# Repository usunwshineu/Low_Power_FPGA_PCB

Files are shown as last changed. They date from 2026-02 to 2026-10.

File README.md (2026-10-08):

# ICE40UP5K LOW POWER FPGA BOARD 

## PCB design

A custom low-power FPGA development board based on the Lattice iCE40UP5K FPGA. 
The board was designed to provide FPGA processing capabilities together with 
power monitoring and common communication interfaces.

The board contains:
* ICE40UP5K FPGA
* FTDI USB interface
* 12MHz clock (used for both the FPGA and FTDI)
* INA226 sensors for measuring power consumption
* I2C and SPI mode 0 PMODs
* SPI Flash memory
* I/O pins
* a reset button
* 3 buttons
* 4 LEDs and 1 RGB LED
  
For different SPI modes you can check <a href="https://0x04.net/~mwk/sbdocs/ice40/FPGA-TN-02010-1-8-iCE40-I2C-and-SPI-Hardened-IP-User-Guide.pdf">this document.

The final assembled board:
Assembled

## PCB programming 

I checked the functionality of the board by running some simple verilog and I used icestorm for creating the bitstream. 
You can check more about Project IceStorm here <a href="https://0x04.net/~mwk/sbdocs/ice40/FPGA-TN-02010-1-8-iCE40-I2C-and-SPI-Hardened-IP-User-Guide.pdf](https://prjicestorm.readthedocs.io/en/latest/overview.html#what-is-project-icestorm">.

The commands I used were: 
* yosys -p "synth_ice40 -top top -json module.json" module.v -> for synthesizing the verilog design
* nextpnr-ice40 --up5k --package sg48 --json module.json --pcf pins.pcf --asc module.asc -> place-and-route
* icepack module.asc module.bin -> converting the result into binary bitstream
* iceprog module.bin -> programming the SPI Flash

Replace module.v, module.json, module.asc, module.bin, and pins.pcf with the corresponding filenames for your design.

## Adding a microprocessor

I used this particular RISC V system, which was built specifically for iCE40UP5k FPGAs: <a href="https://github.com/emeb/up5k_riscv/blame/master/README.md">up5k_riscv.

I modified the icestorm/up5k_riscv.pcf file with my own pins. Any other modified files were added to this repository.
In main.c file I wrote a code to read the power consumption (using I2C communication with the INA226 sensors) and display it on an OLED (SPI communication). 

This provides a complete demonstration of the board's:

* RISC V processing system
* I2C communication
* SPI communication
* Power monitoring
* OLED display interface

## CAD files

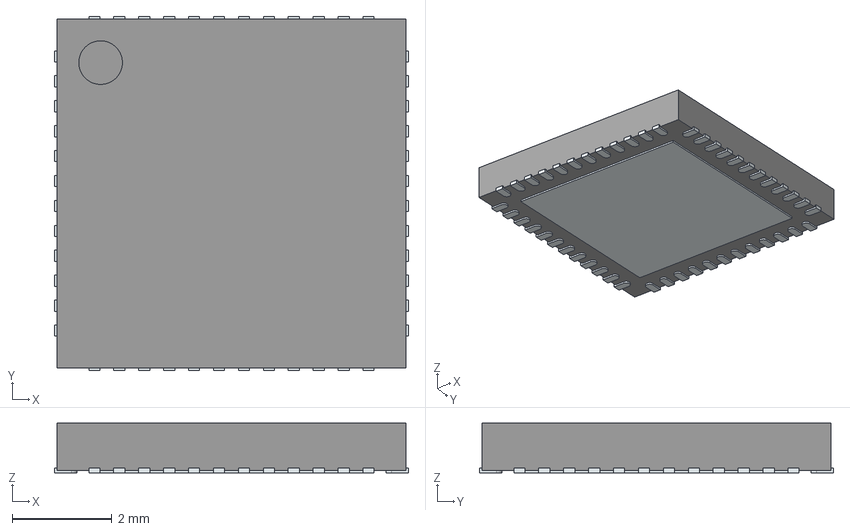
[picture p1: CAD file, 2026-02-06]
librarii/ICE5LP2K-SG48ITR/3D/ICE5LP2K-SG48ITR.stp
7.10 x 7.10 x 1.00 mm
ThermalPin
PinsArrayLR
PinsArrayTB

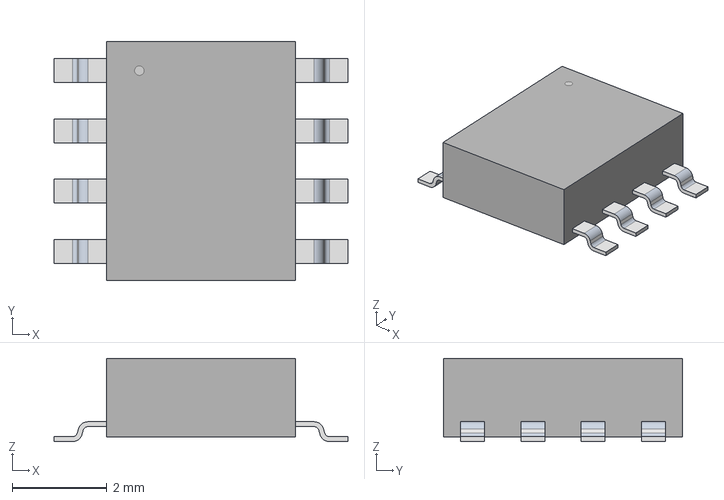
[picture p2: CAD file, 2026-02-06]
librarii/SOP8_150MIL_MAC.iges
6.20 x 5.03 x 1.75 mm

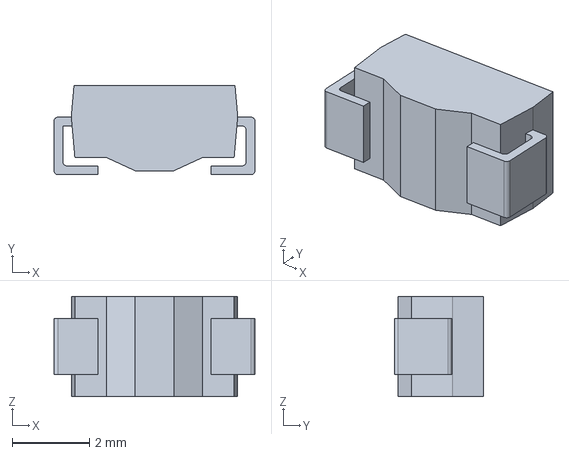
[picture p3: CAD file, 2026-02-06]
librarii/TVS_DIODE/SMAJ5.0A/3D/SMAJ5.0A.stp
5.21 x 2.31 x 2.60 mm

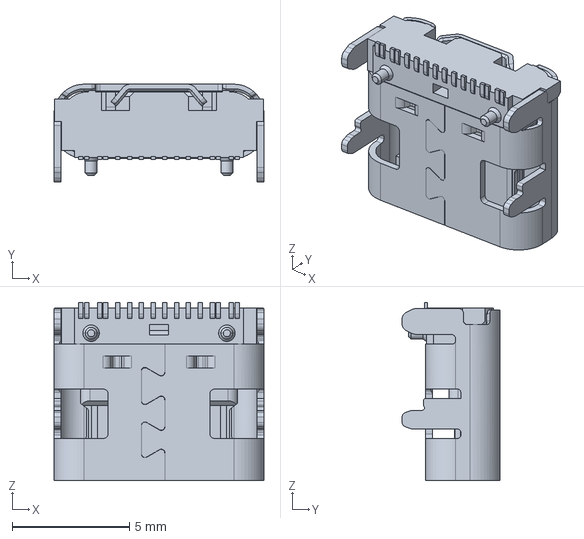
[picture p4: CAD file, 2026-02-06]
librarii/USB-C_connector/10155435-00011LF/3D/10155435-00011LF.stp
8.94 x 4.16 x 7.60 mm

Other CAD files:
librarii/ICE5LP2K-SG48ITR/Allegro/qfn50p700x700x100-49n-d.psm
librarii/ICE5LP2K-SG48ITR/DEHDL/ice5lp2k_sg48itr/chips/chips.prt
librarii/TVS_DIODE/SMAJ5.0A/Allegro/diom5026x229n.psm
librarii/TVS_DIODE/SMAJ5.0A/DEHDL/smaj5.0a/chips/chips.prt

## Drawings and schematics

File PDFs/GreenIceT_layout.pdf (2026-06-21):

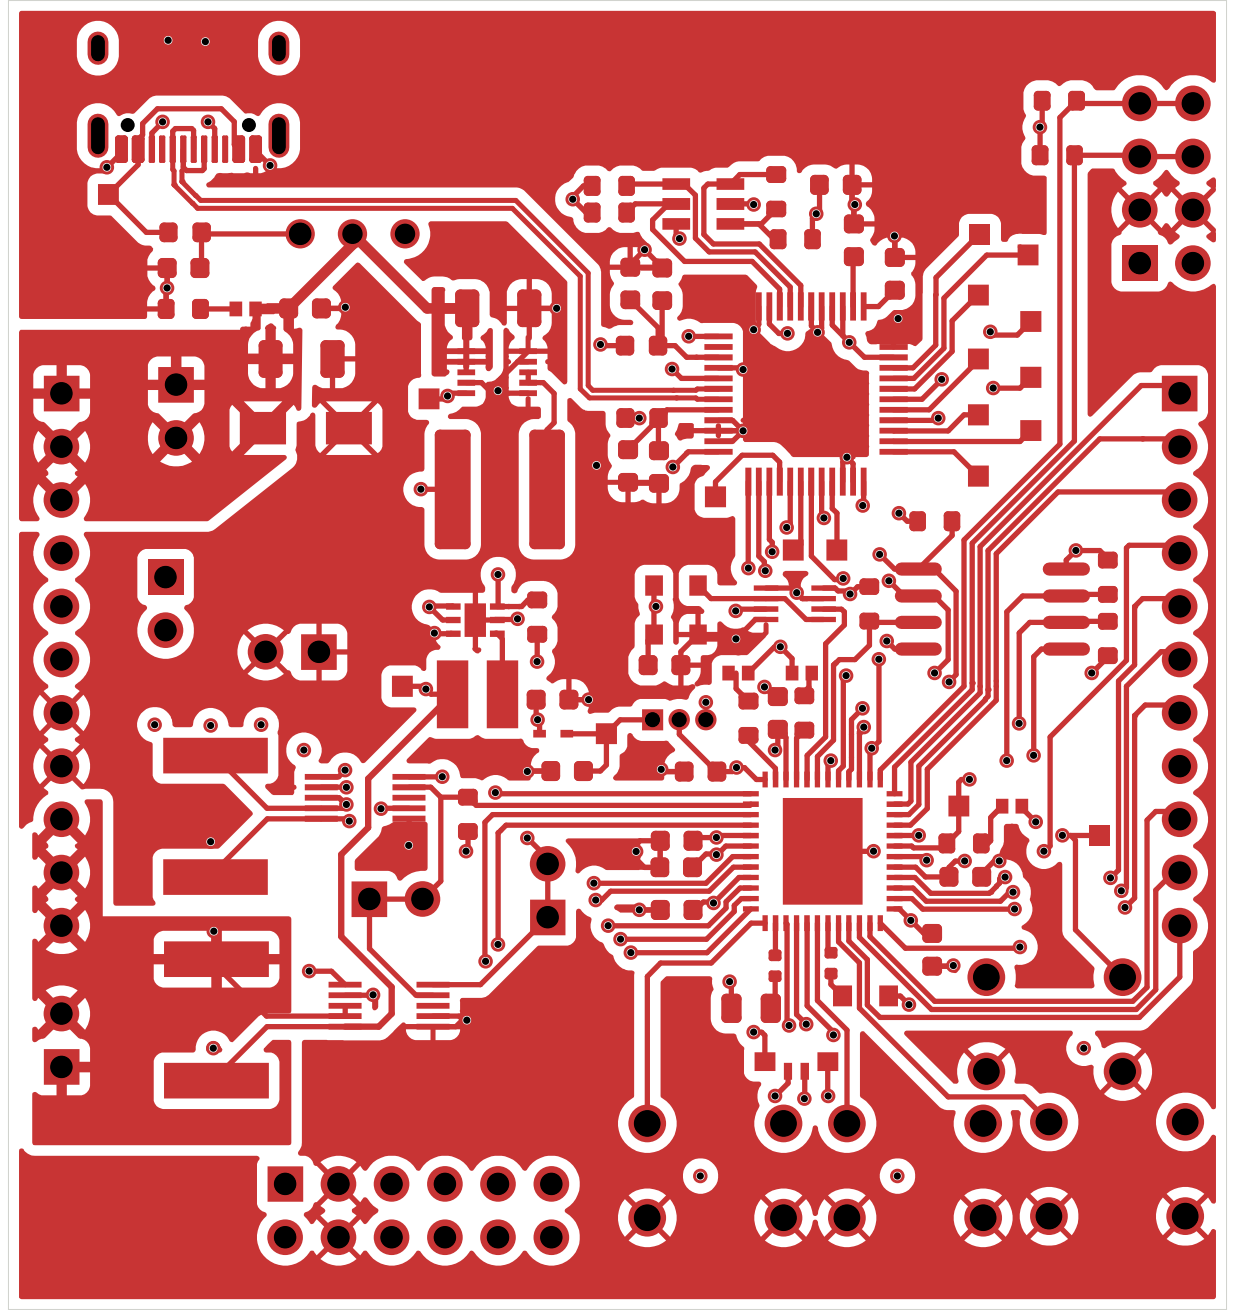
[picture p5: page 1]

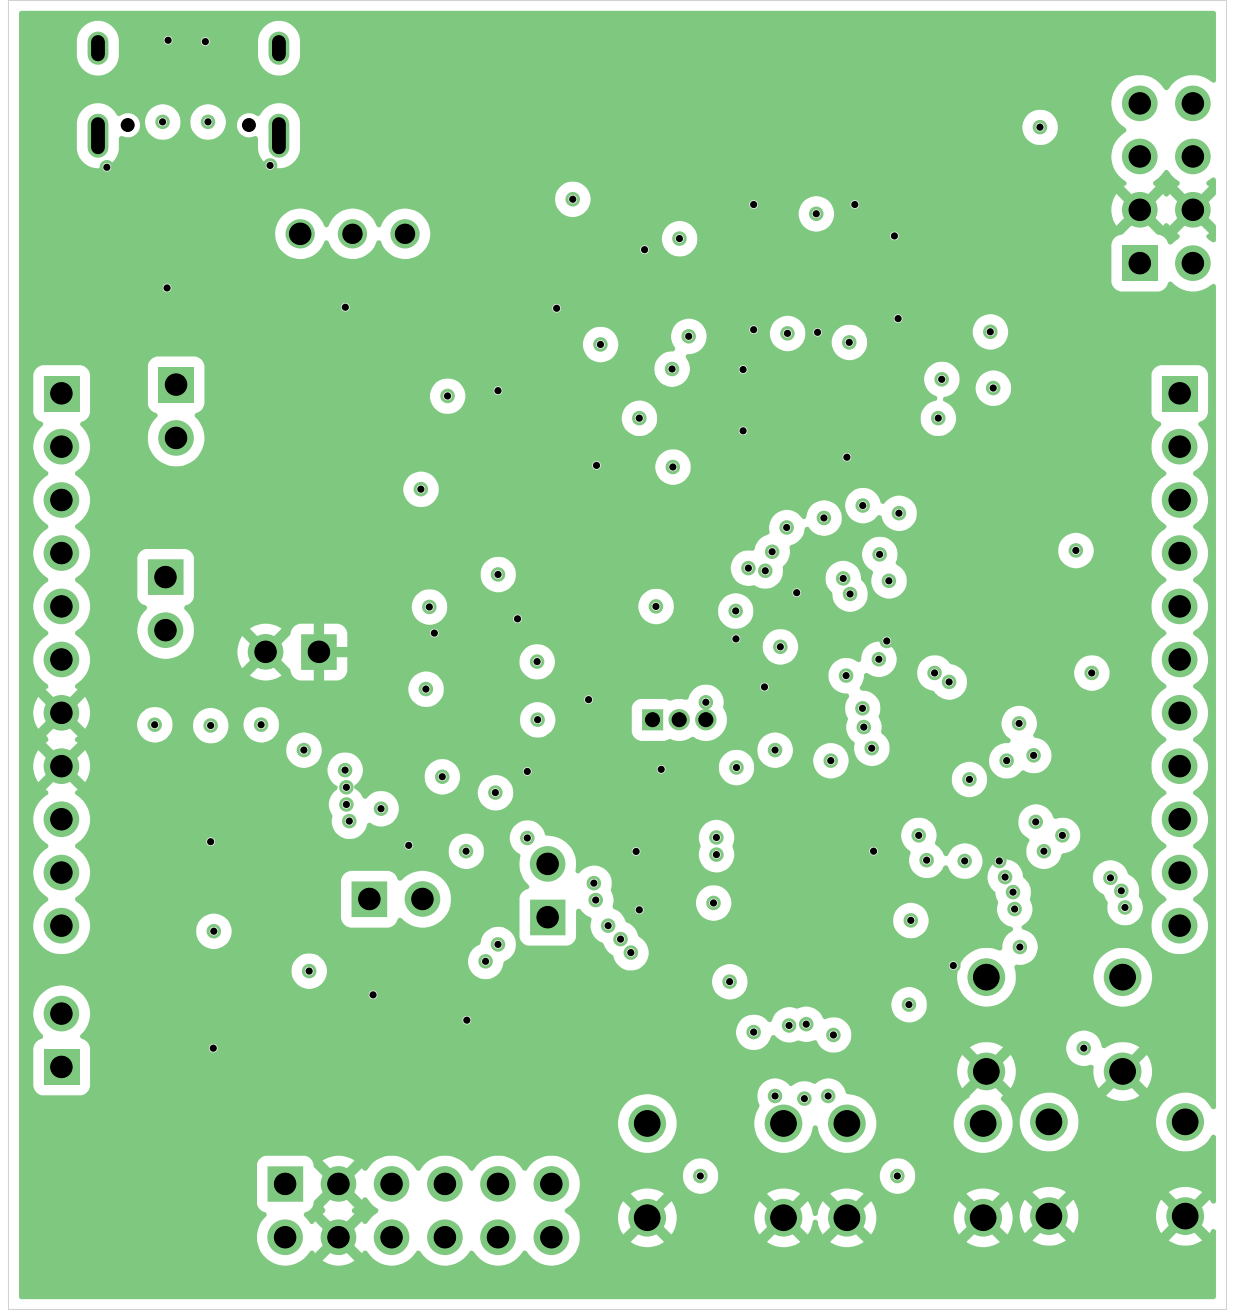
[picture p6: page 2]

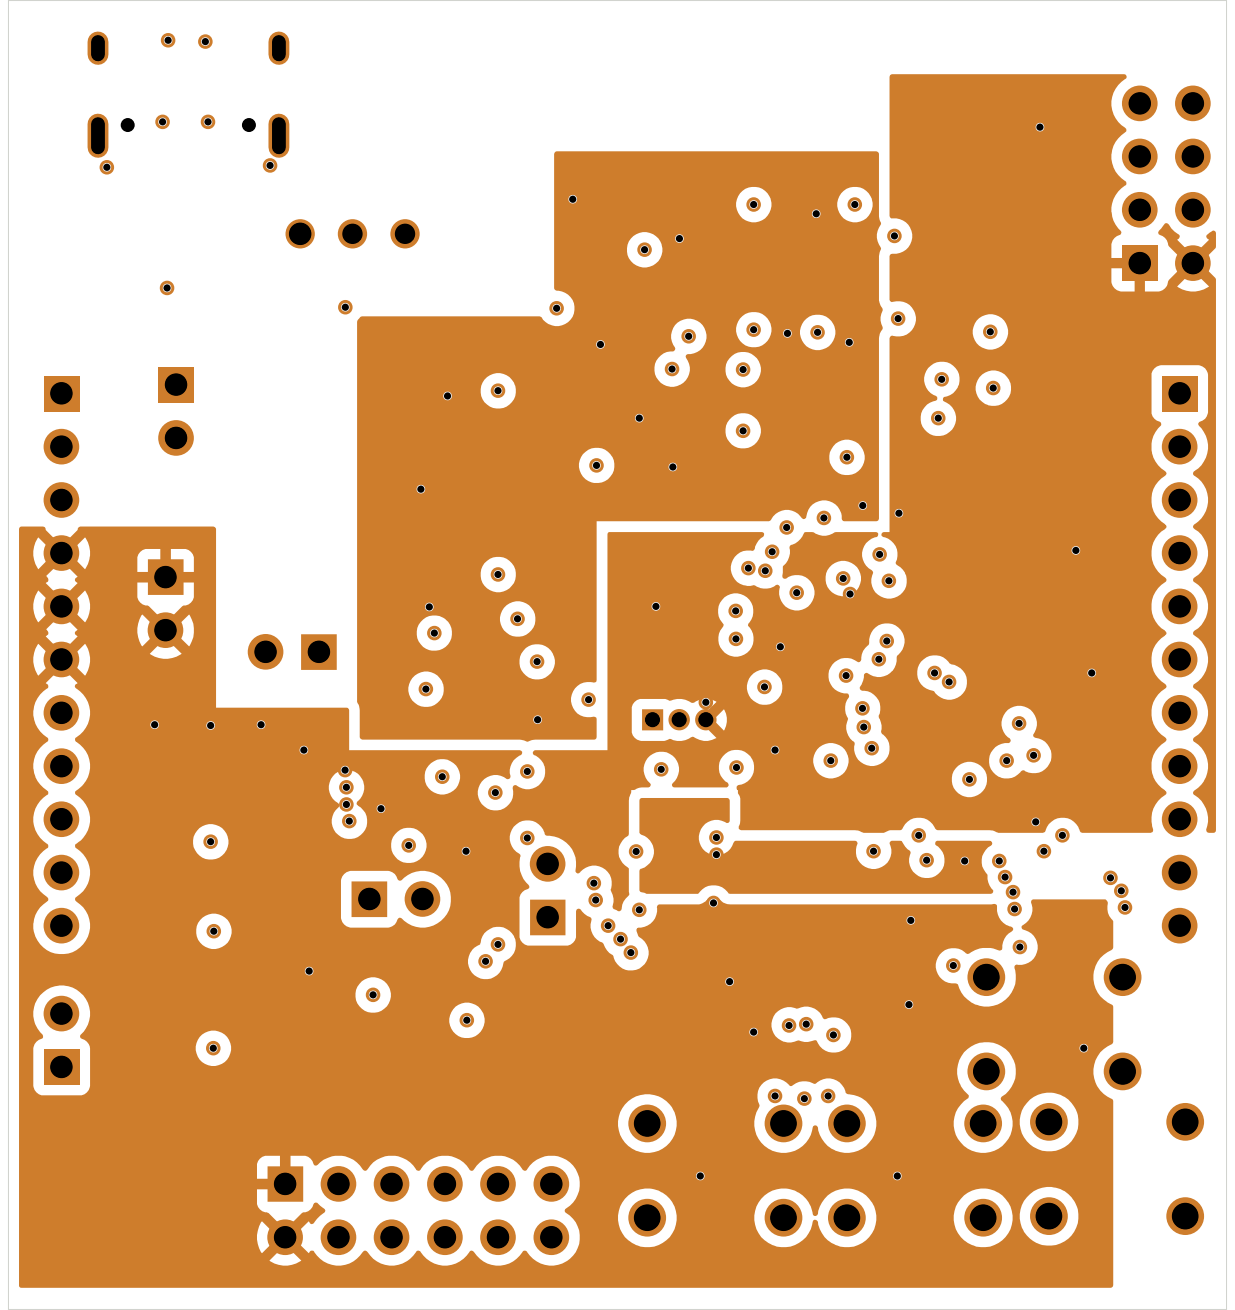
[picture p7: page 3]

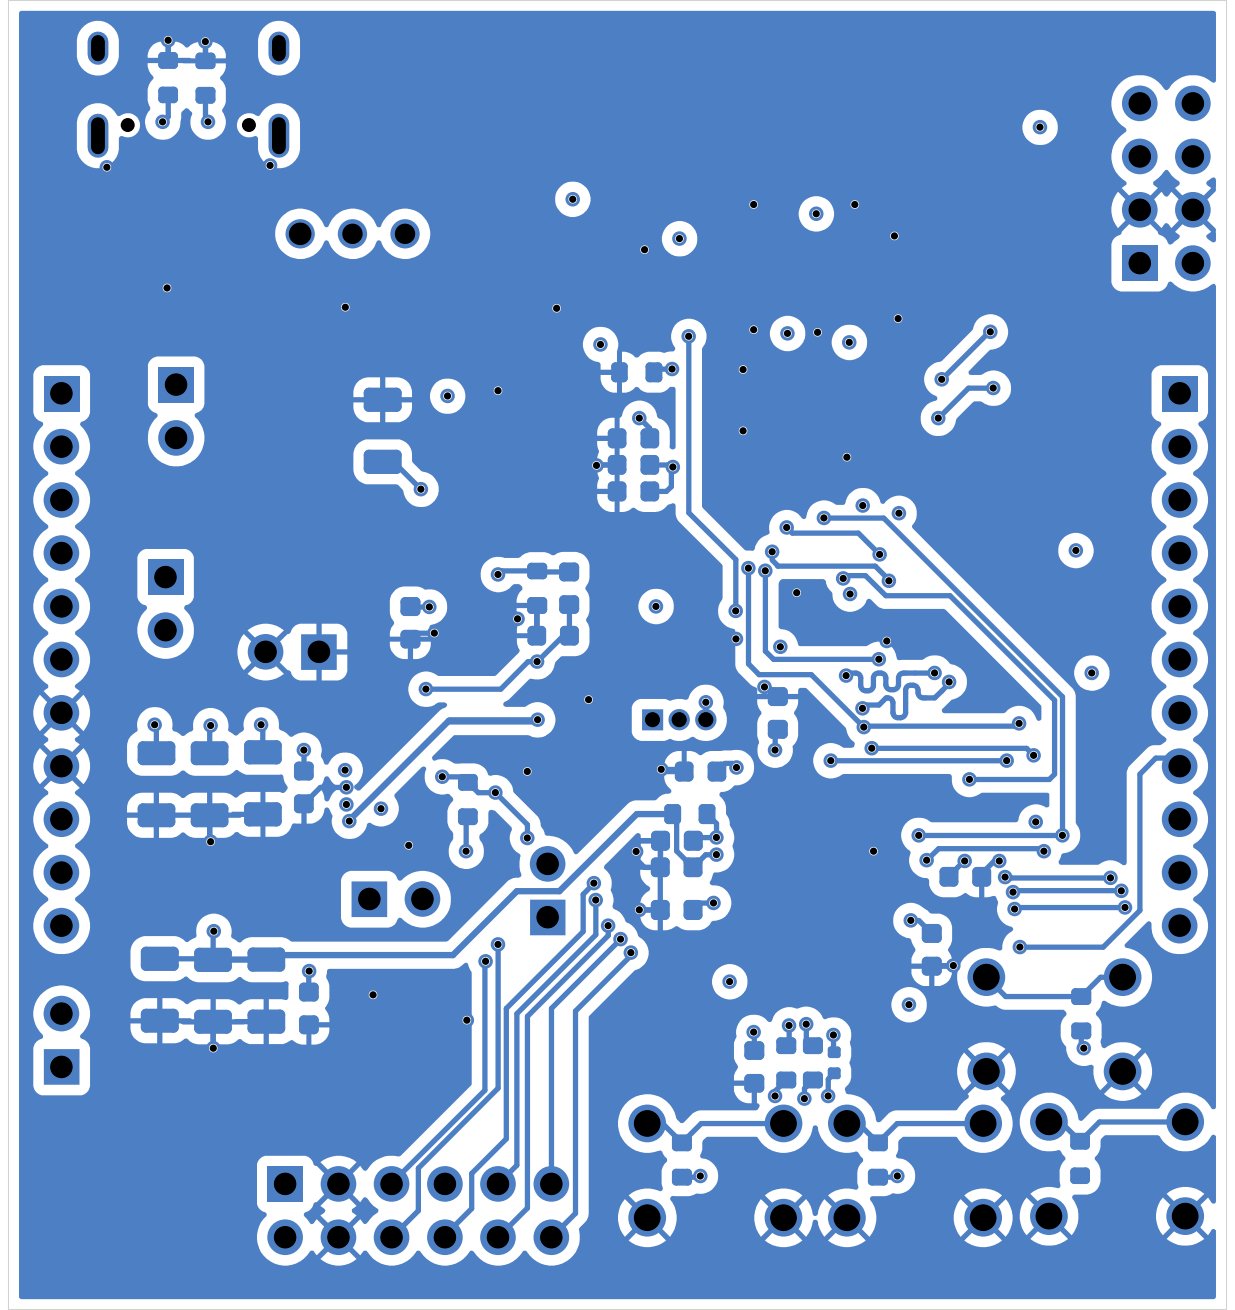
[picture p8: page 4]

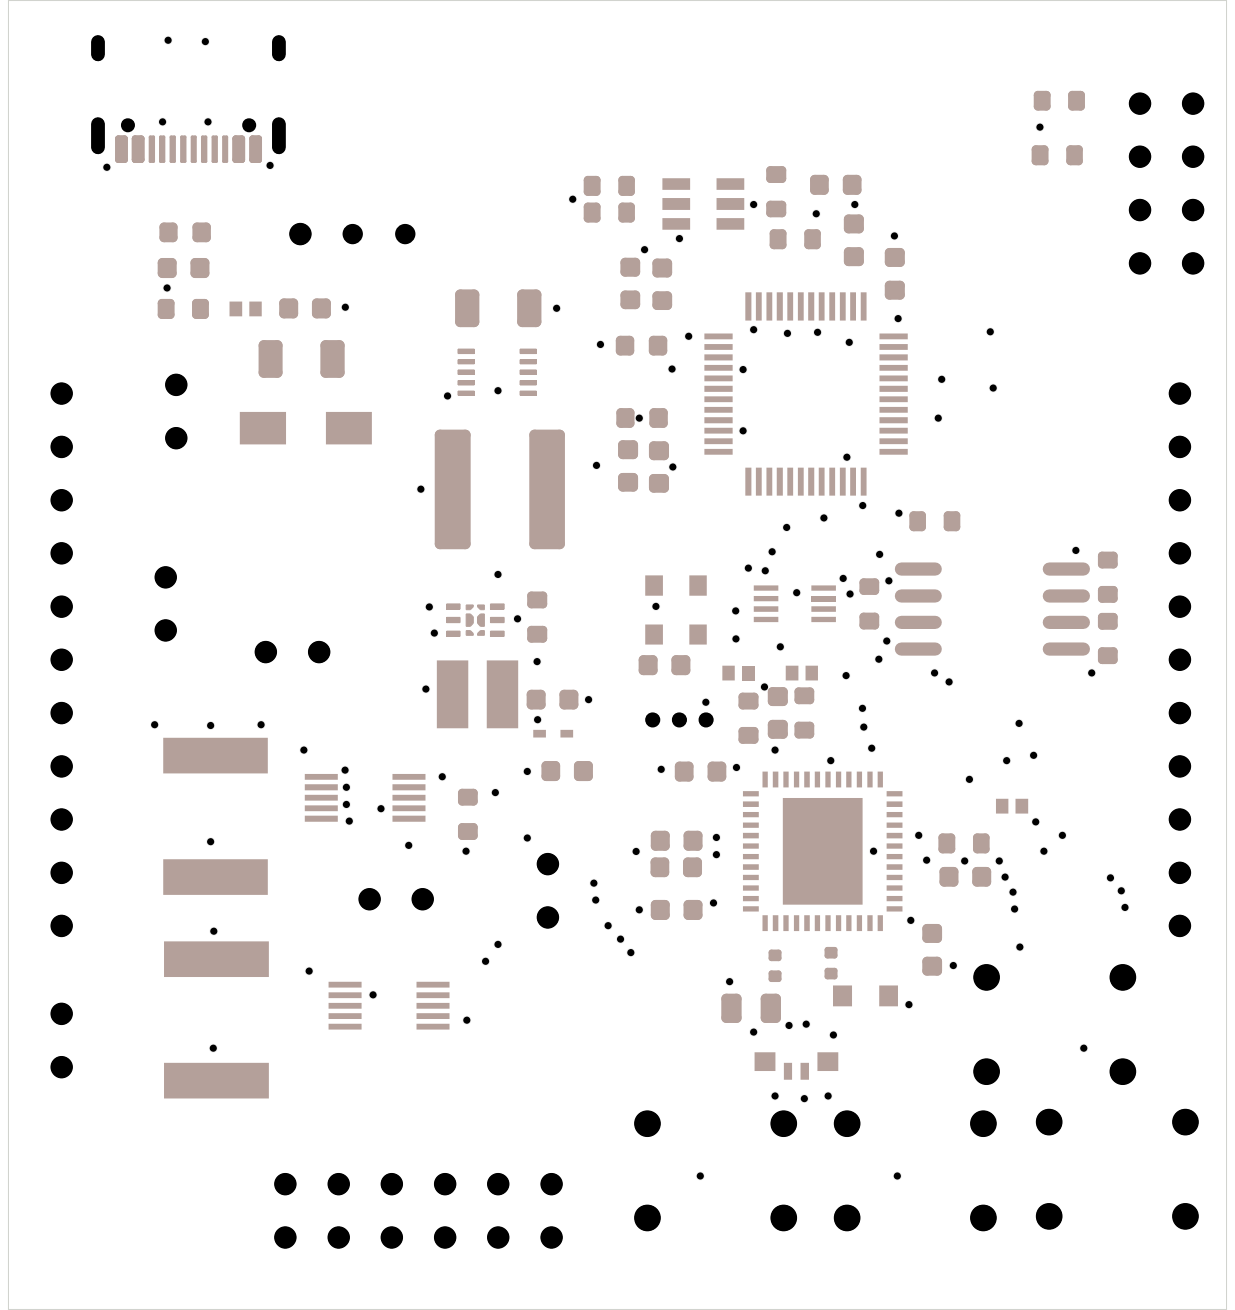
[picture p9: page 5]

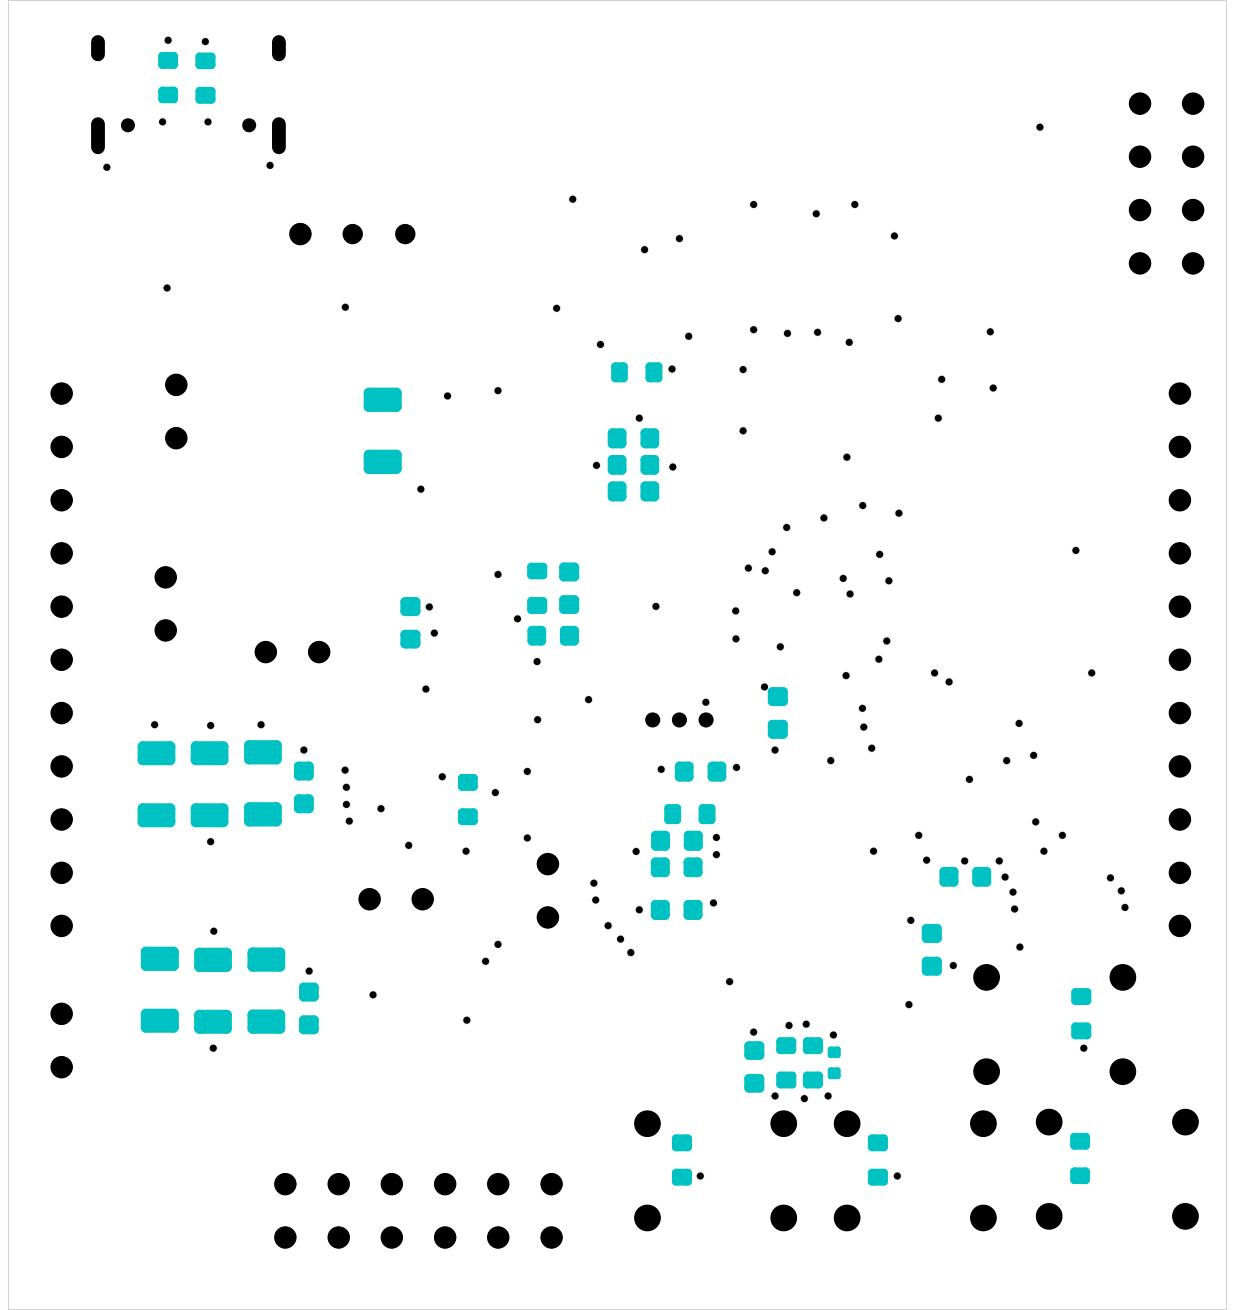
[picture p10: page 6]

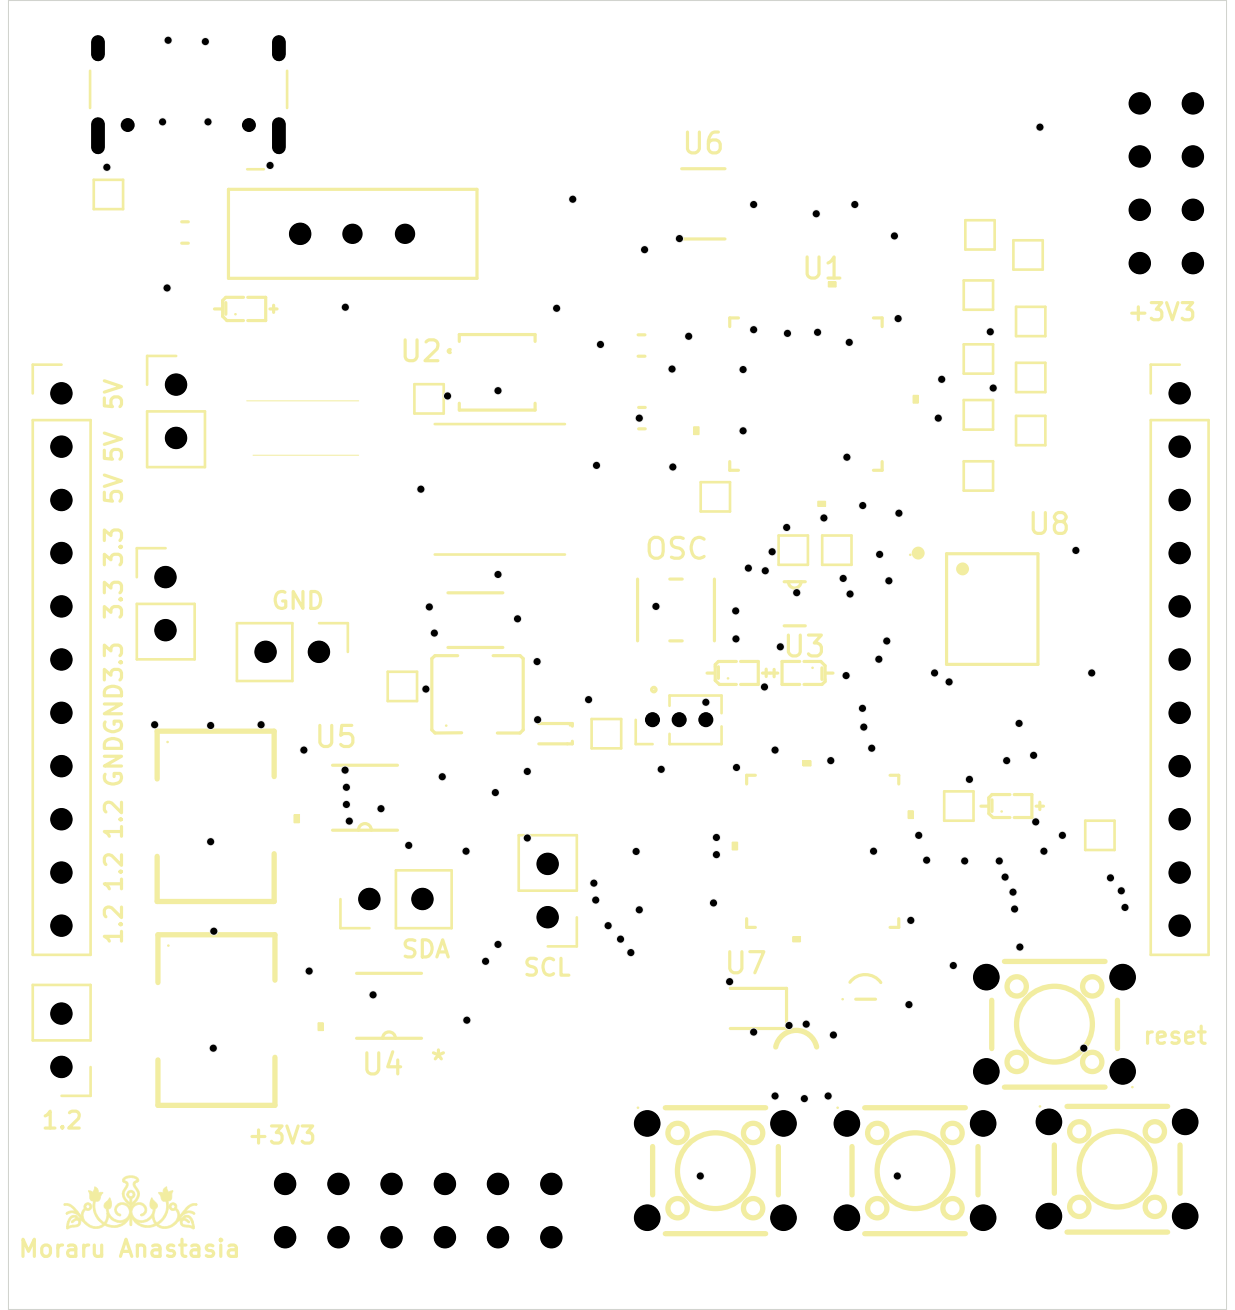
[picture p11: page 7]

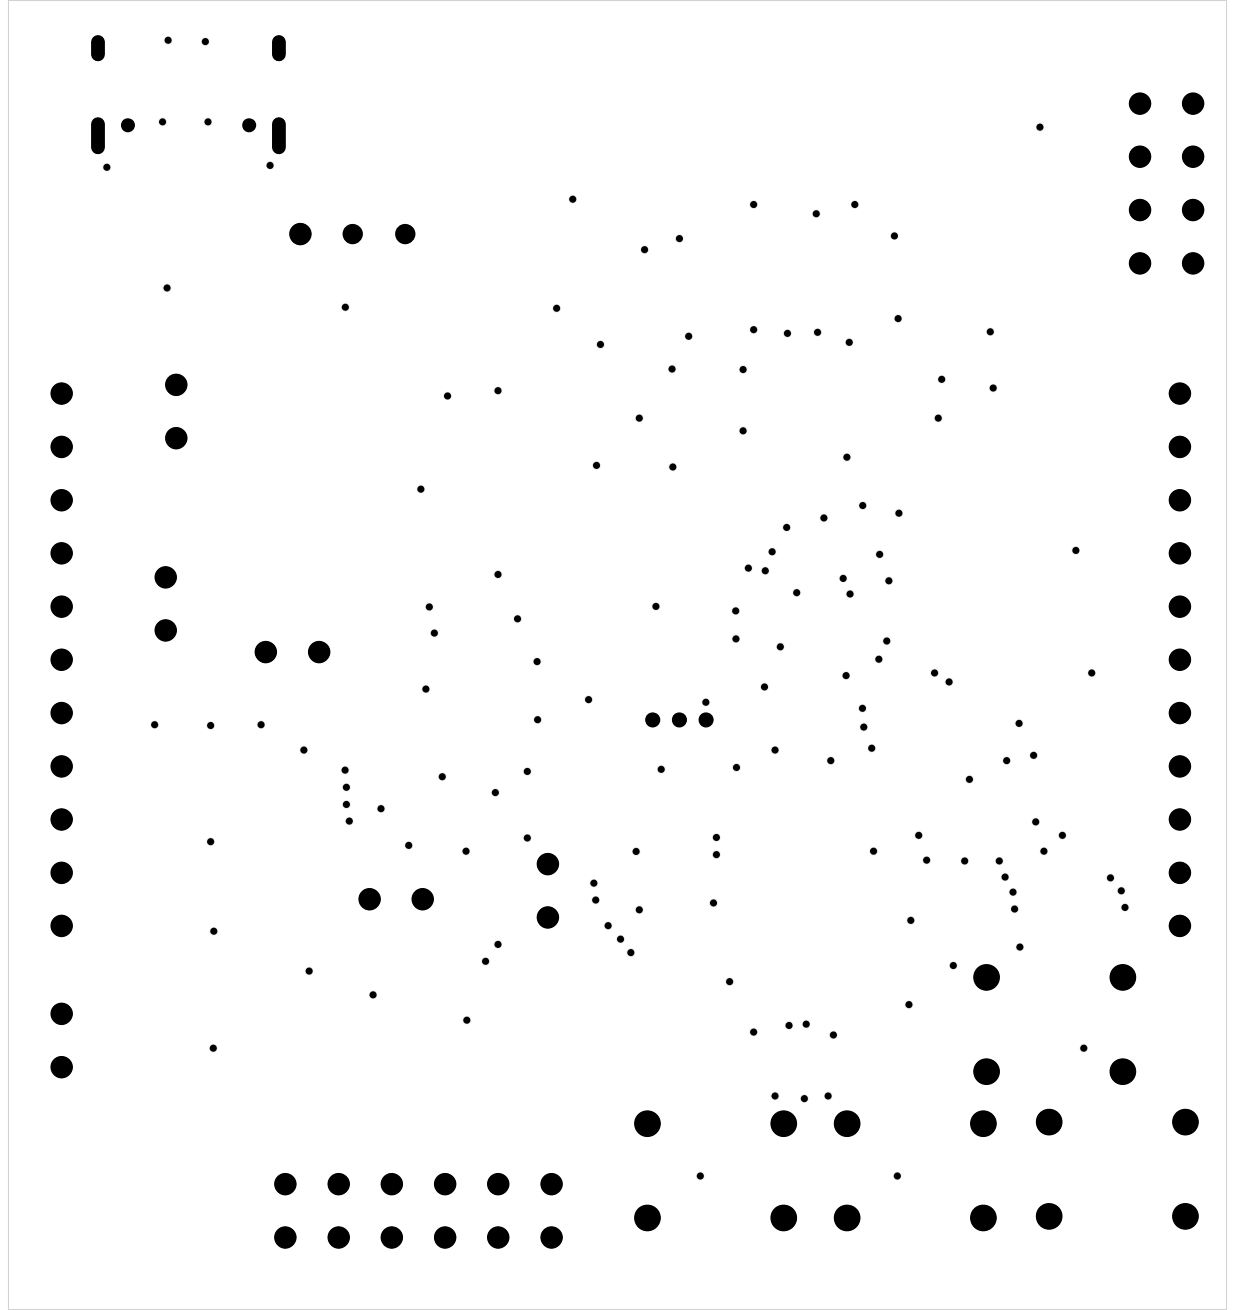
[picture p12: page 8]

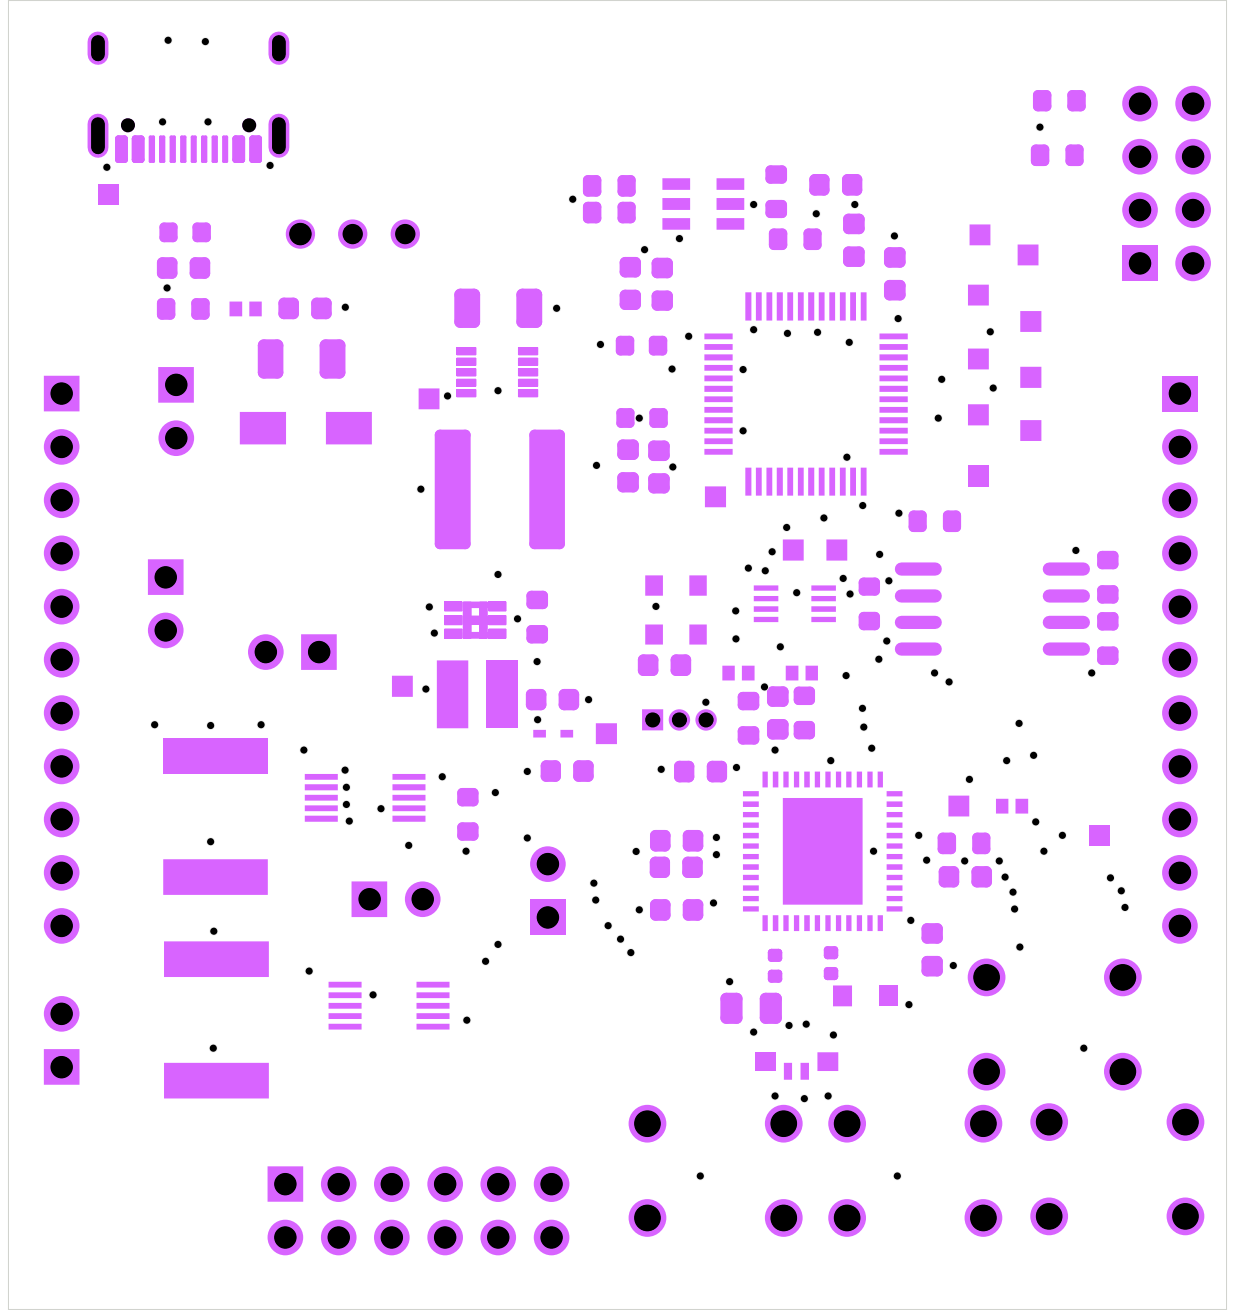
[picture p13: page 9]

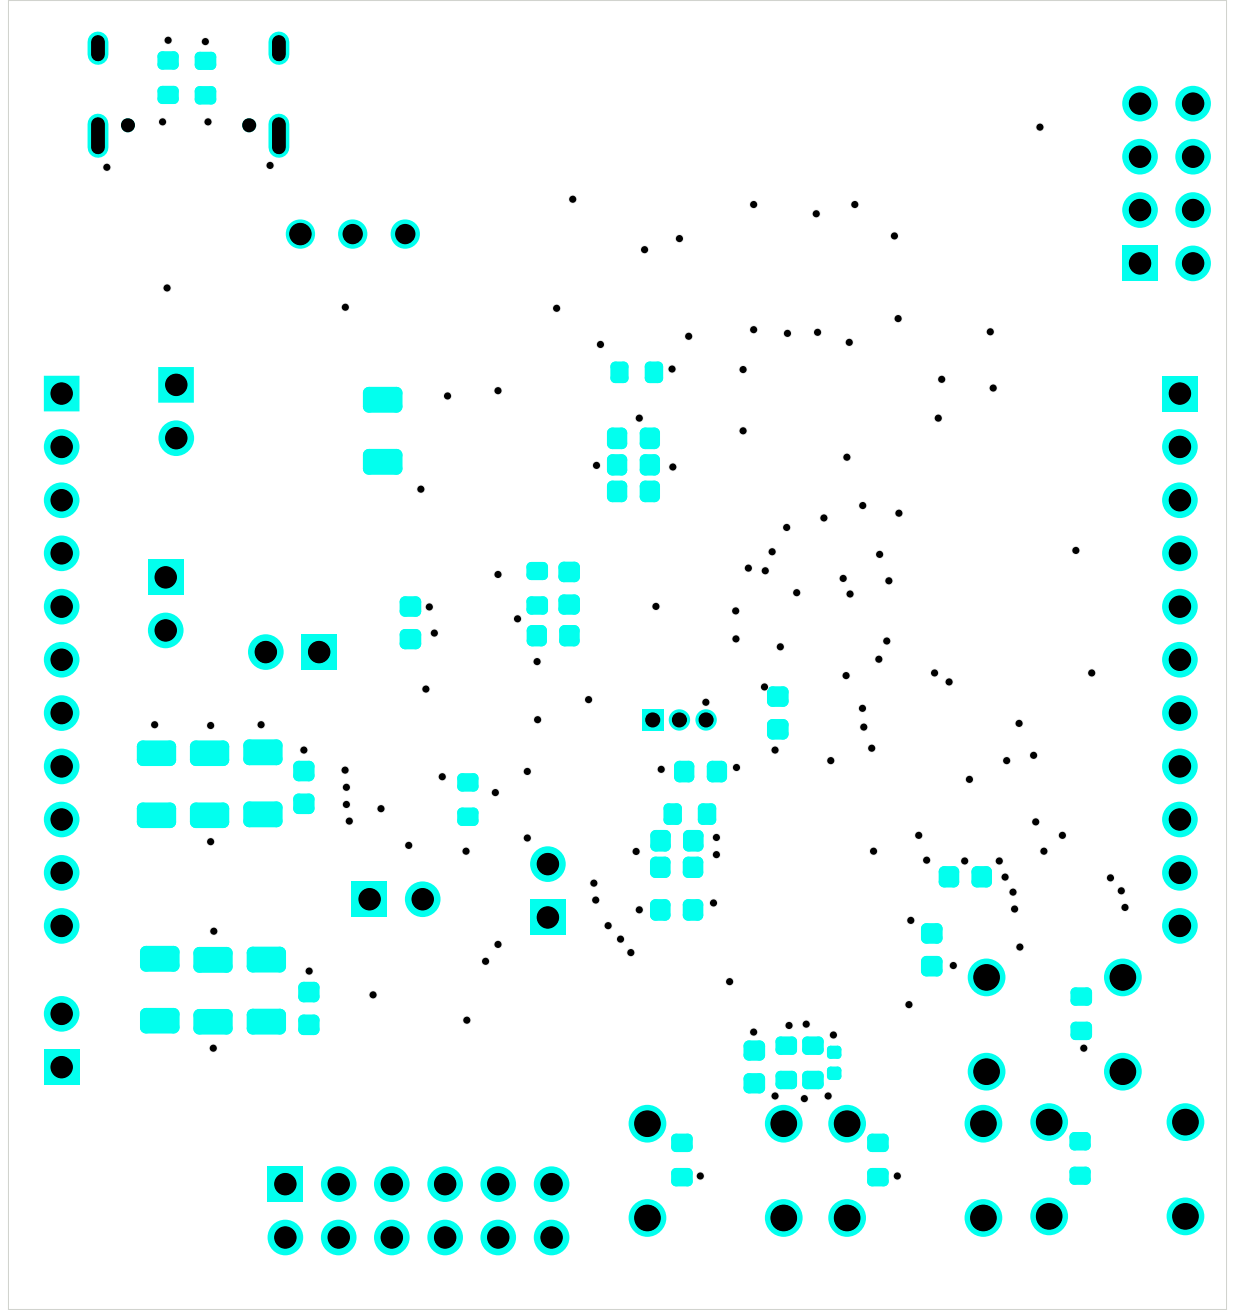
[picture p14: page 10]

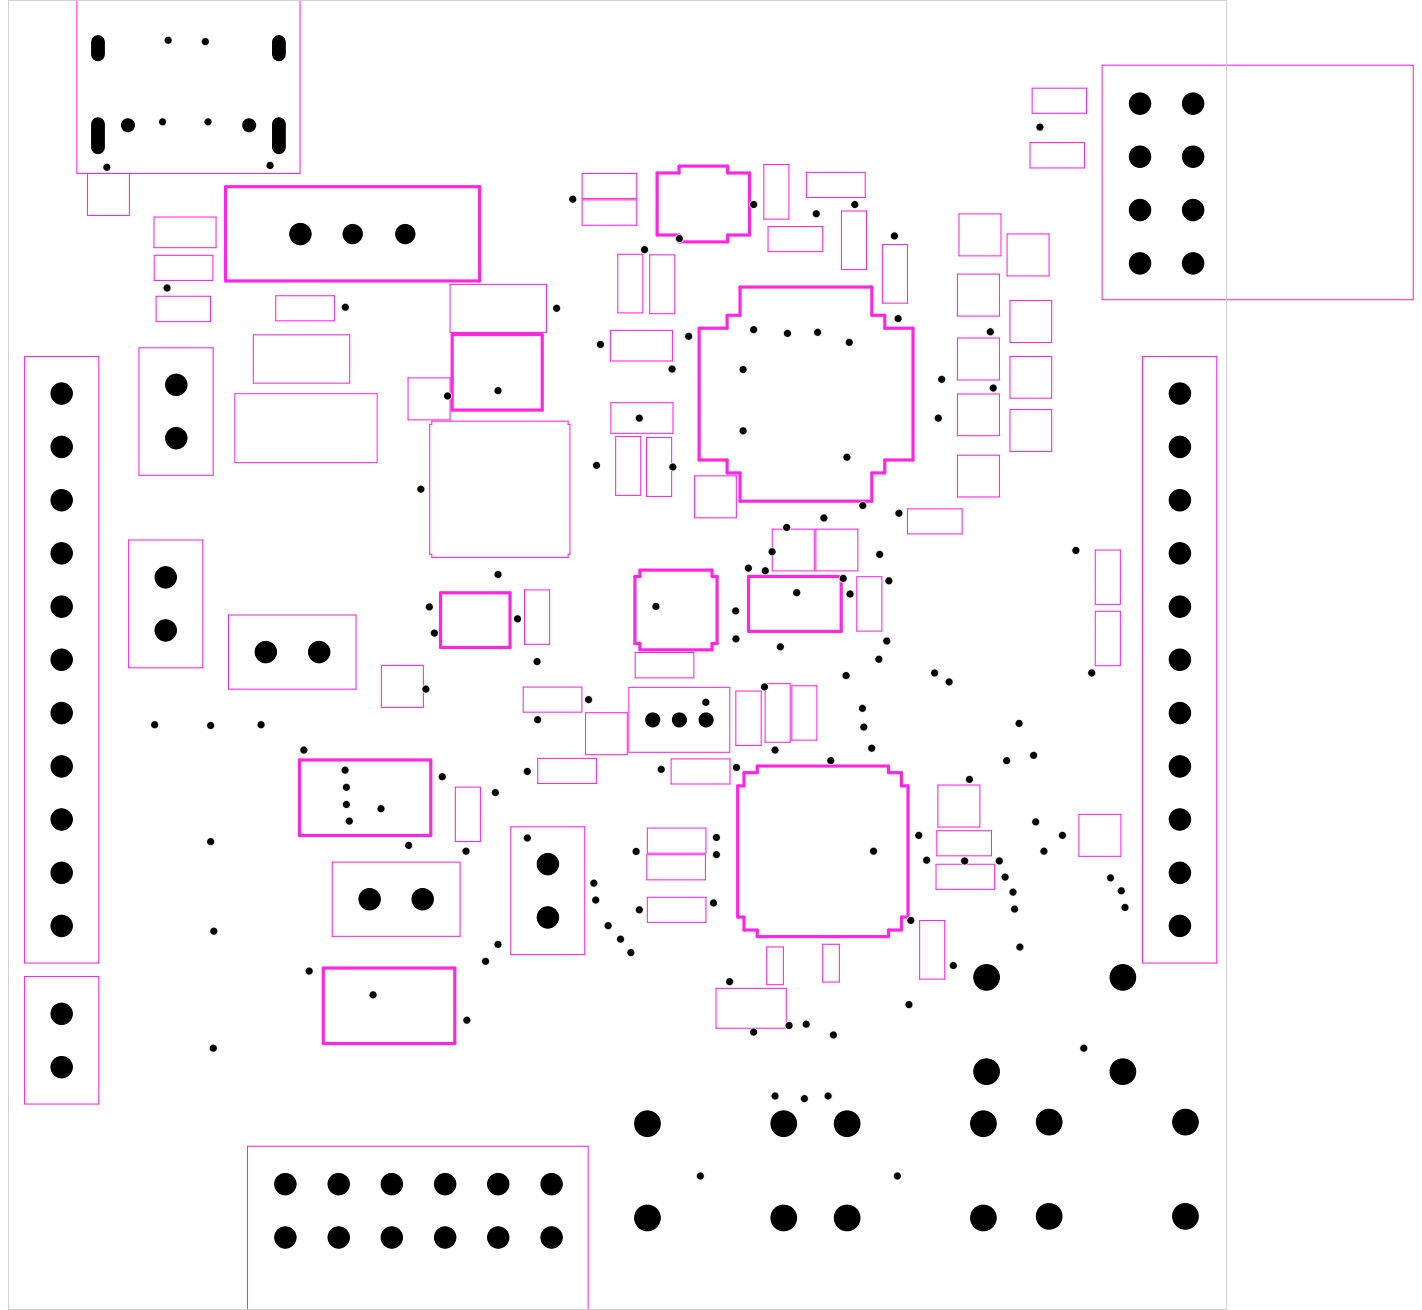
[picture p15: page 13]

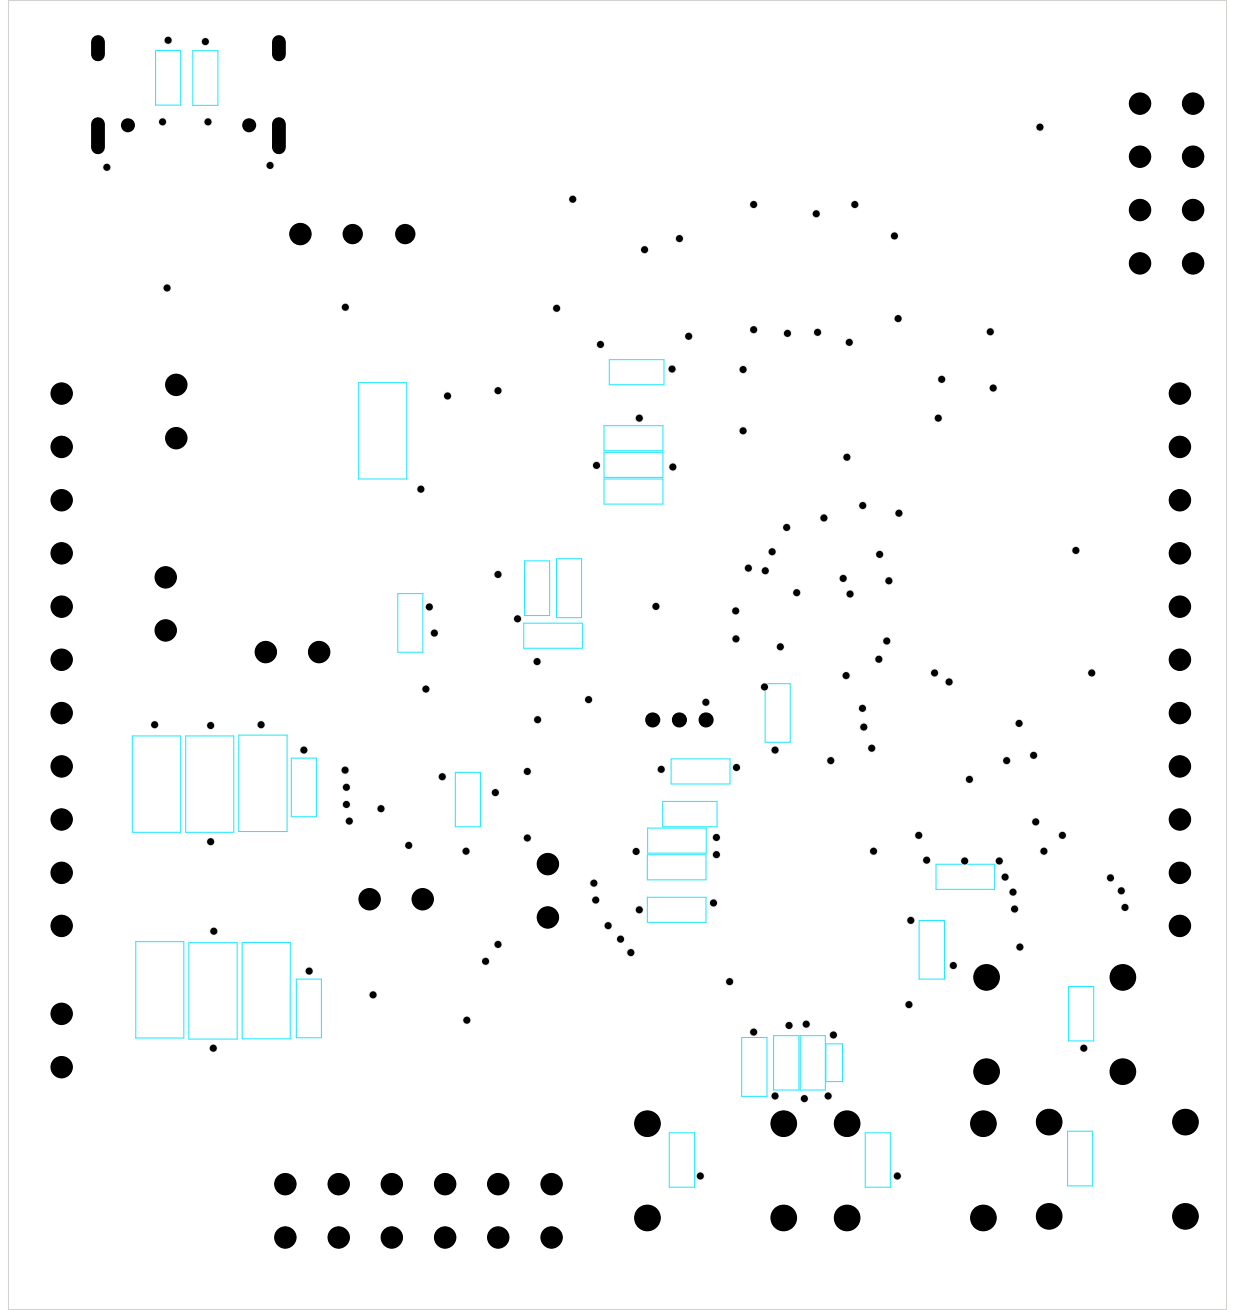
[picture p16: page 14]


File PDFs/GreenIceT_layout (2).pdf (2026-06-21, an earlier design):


D Date: KiCad; E.D.A. 9.0.6 Size: A4; Rev:

Id: 2/1 Title: File: First_try.kicad_pcb Sheet:


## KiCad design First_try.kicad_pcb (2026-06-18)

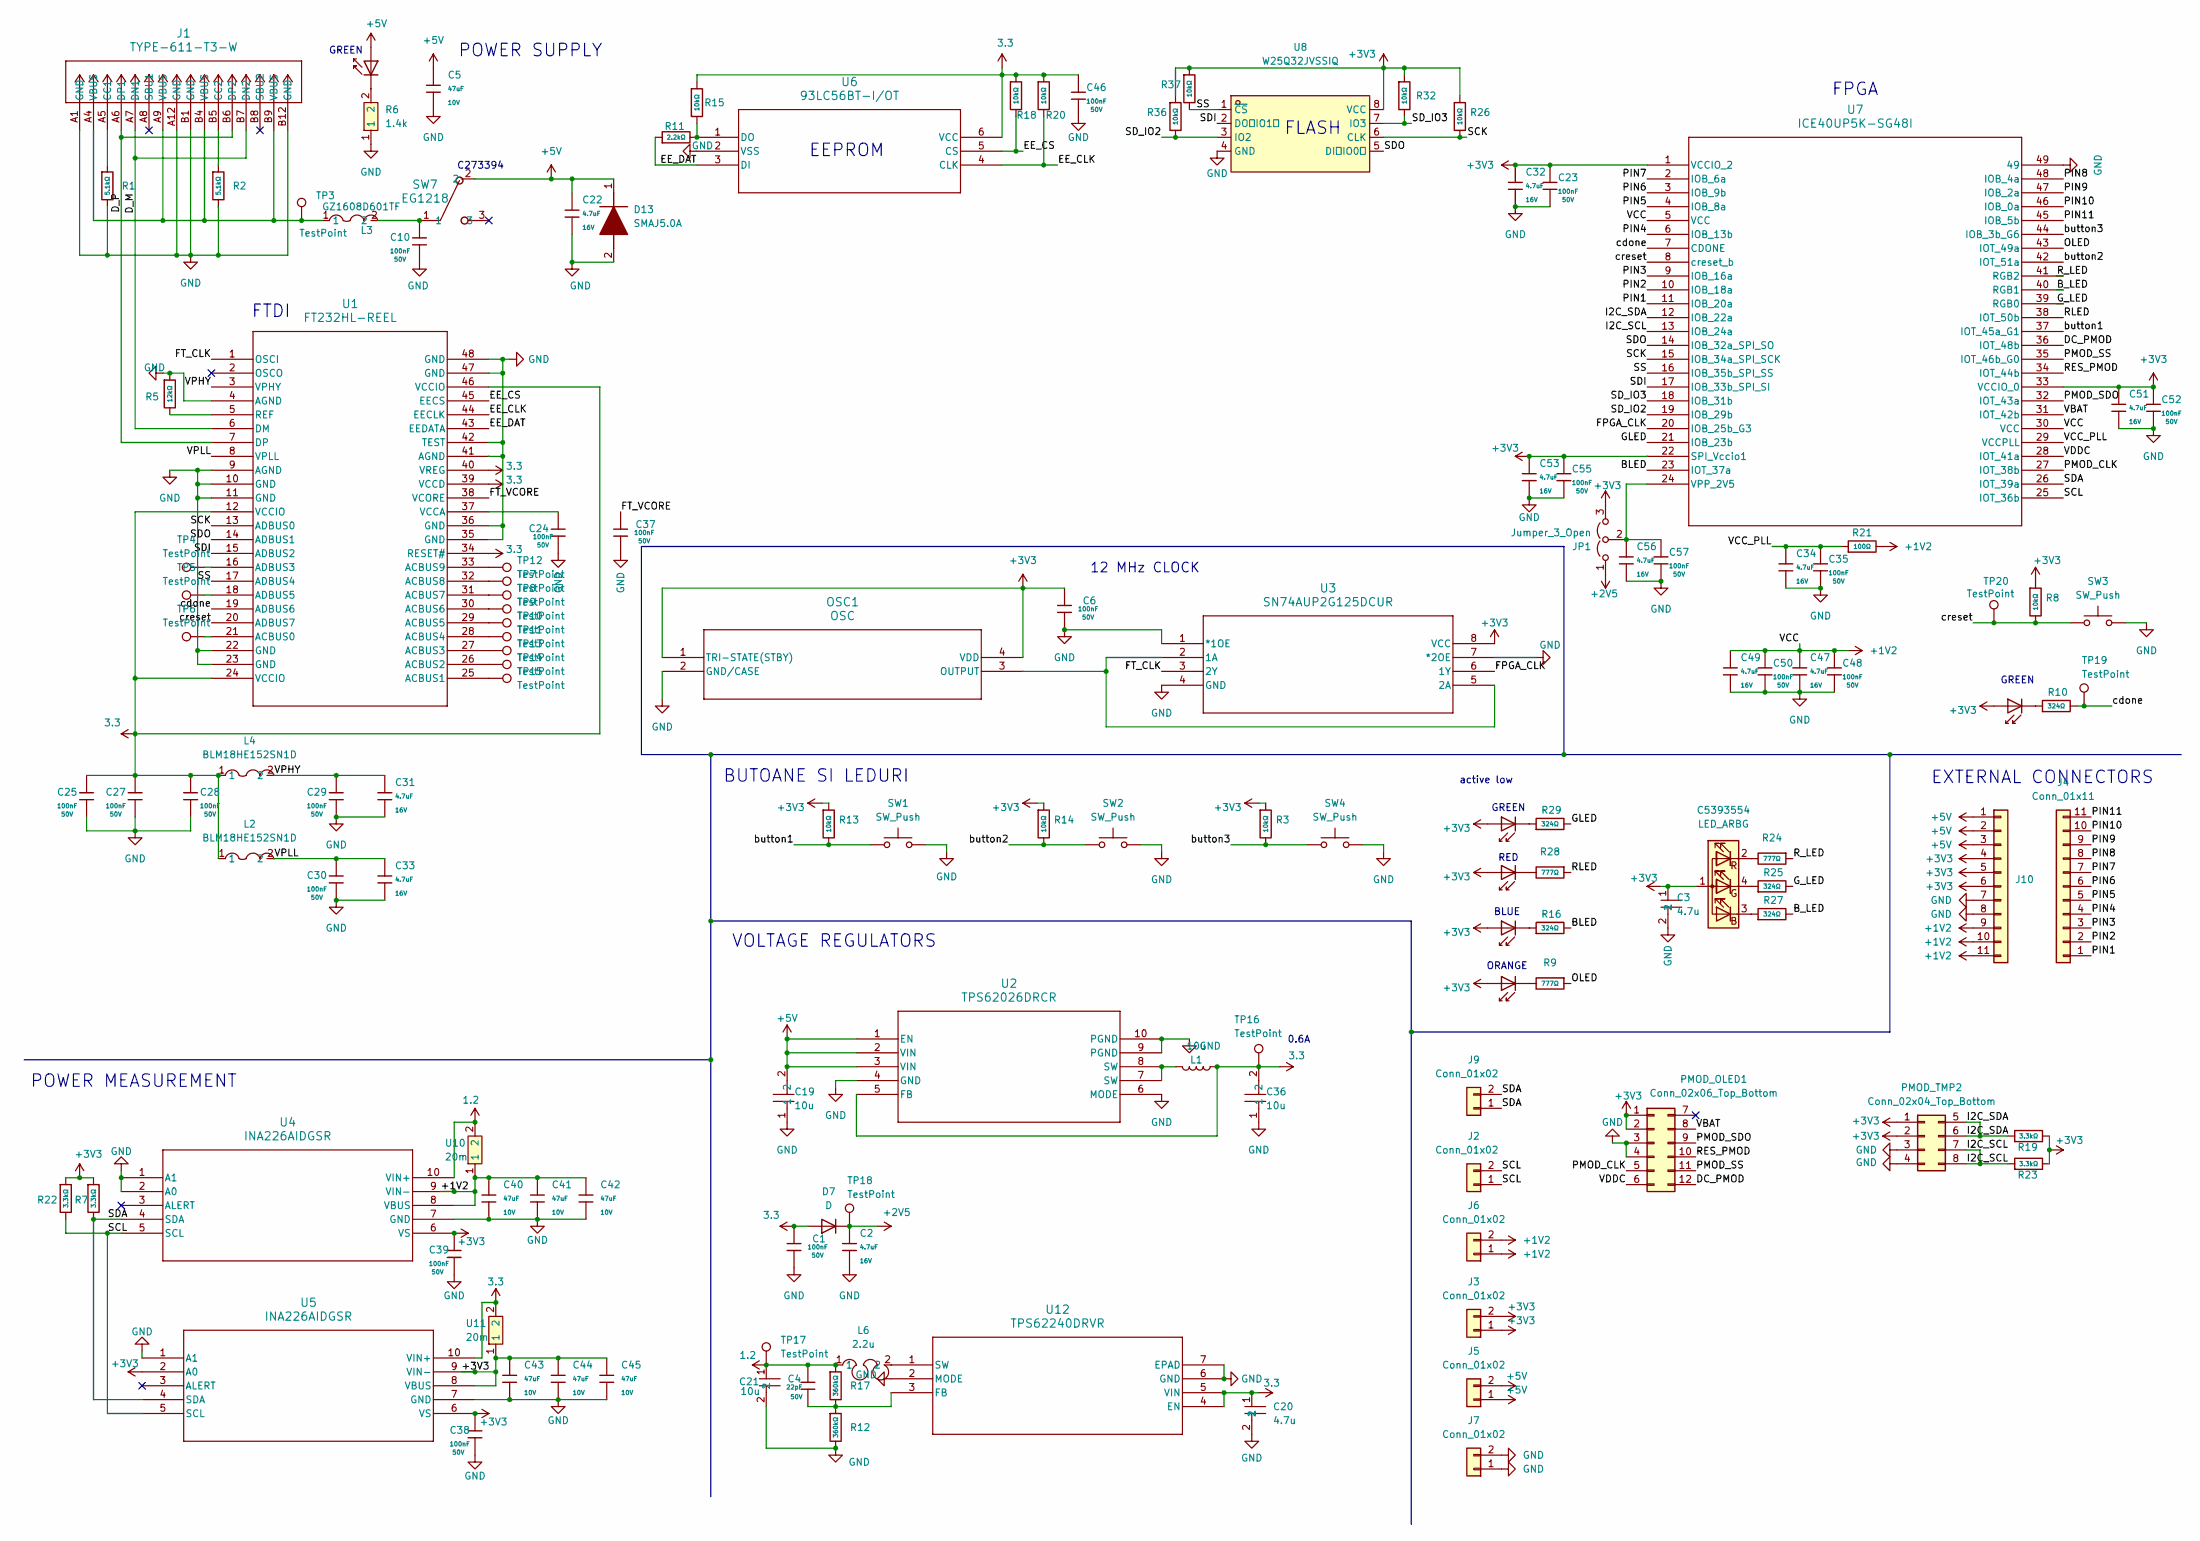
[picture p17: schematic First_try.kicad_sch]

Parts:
C1, C6, C10, C23, C24, C25, C27, C28, C29, C30, C35, C37, C38, C39, C46, C48, C50, C52, C55, C57: 100nF; C_0603; Voltage Rated 50V; Tolerance ±10%; Part CC0603KRX7R9BB104; LCSC C14663
C2, C22, C31, C32, C33, C34, C47, C49, C51, C53, C56: 4.7uF; C_0603; Voltage Rated 16V; Tolerance ±10%; Part CL10A475KO8NNNC; LCSC C19666
C3, C20: 4.7u; C_0603; LCSC Part C71631
C4: 22pF; C_0603; Voltage Rated 50V; Tolerance ±5%; Part CL10C220JB8NNNC; LCSC C1653
C5, C40, C41, C42, C43, C44, C45: 47uF; C_1206; Voltage Rated 10V; Tolerance ±20%; Part CL31A476MPHNNNE; LCSC C96123
C19, C36: 10u; C_1206; LCSC Part C92789
C21: 10u; C_0603; LCSC Part C77041
C5393554: LED_ARBG; RGB_LED; JLCPCB C5393554
D1, D2, D3: LD274; LED-SMD_L1.0-W0.5-RD; JLCPCB C5875752
D4: LD274; D_0805; JLCPCB C5366382
D5: LD274; LED-SMD_L1.0-W0.5-RD; JLCPCB C5354973
D6: LD274; LED-SMD_L2.1-W1.0-FD_UMD960; JLCPCB C5588281
D7: D; D2V5; JLCPCB C727112
D13: SMAJ5.0A; SMAJ; Manufacturer_Part_Number SMAJ5.0A; Mouser Part Number 652-SMAJ5.0A
J1: TYPE-611-T3-W; USB_C_Receptacle_HCTL_HC-TYPE-C-16P-01A; JLCPCB C2689844
J2, J3, J5, J6, J7, J9: Conn_01x02; PinHeader_1x02_P2.54mm_Vertical; JLCPB C32713268
J4, J10: Conn_01x11; PinHeader_1x11_P2.54mm_Vertical
JP1: Jumper_3_Open; PinHeader_1x03_P1.27mm_Vertical; JLCPCB C24980
L1: 10u; L_APV_ANR6045; JLCPCB C5259068
L2, L4: BLM18HE152SN1D; L_0603; LCSC Part C82155
L3: GZ1608D601TF; L_0603; LCSC Part C1002
L6: 2.2u; IND-SMD_L3.0-W3.0_LPS3015-222ML; LCSC Part C2844756
OSC1: OSC; ASE-3.2X2.5_ABR; JLCPCB C596950
PMOD_OLED1: Conn_02x06_Top_Bottom; PinSocket_2x06_P2.54mm_Horizontal_edit; JLCPCB C5333437
PMOD_TMP2: Conn_02x04_Top_Bottom; PinSocket_2x04_P2.54mm_Horizontal_edit; JLCPCB C7529541
R1, R2: 5.1kΩ; R_0603; Overload Voltage (Max) 75V; Tolerance ±1%; Part 0603WAF5101T5E; LCSC C23186
R3, R8, R13, R14, R15, R18, R20, R26, R32, R36, R37: 10kΩ; R_0603; Overload Voltage (Max) 75V; Tolerance ±1%; Part 0603WAF1002T5E; LCSC C25804
R5: 12kΩ; R_0603; Overload Voltage (Max) 75V; Tolerance ±1%; Part 0603WAF1202T5E; LCSC C22790
R6: 1.4k; R_0603; LCSC Part C25957
R7, R19, R22, R23: 3.3kΩ; R_0603; Overload Voltage (Max) 75V; Tolerance ±1%; Part 0603WAF3301T5E; LCSC C22978
R9, R24, R28: 777Ω; R_0402; Overload Voltage (Max) 75V; Tolerance ±1%; Part 0603WAF1001T5E; LCSC C852914
R10, R16, R25, R27, R29: 324Ω; R_0603; Overload Voltage (Max) 75V; Tolerance ±1%; Part 0603WAF5600T5E; LCSC C12963
R11: 2.2kΩ; R_0603; Overload Voltage (Max) 75V; Tolerance ±1%; Part 0603WAF2201T5E; LCSC C4190
R12, R17: 360kΩ; R_0603; Overload Voltage (Max) 75V; Tolerance ±1%; Part 0603WAF3603T5E; LCSC C23146
R21: 100Ω; R_0603; Overload Voltage (Max) 75V; Tolerance ±1%; Part 0603WAF1000T5E; LCSC C22775
SW1, SW2, SW3, SW4: SW_Push; SW_push; JLCPCB C455095
SW7: EG1218; SW_1218_EWI; JLCPCB C273394
TP3, TP4, TP5, TP6, TP7, TP8, TP9, TP10, TP11, TP12, TP13, TP14, TP15, TP16, TP17, TP18, TP19, TP20: TestPoint; TestPoint_Pad_1.0x1.0mm
U1: FT232HL-REEL; FTDI; JLCPCB C51997
U2: TPS62026DRCR; Vreg3_3; JLCPCB C2071183
U3: SN74AUP2G125DCUR; Buffer; JLCPCB C2862074
U4, U5: INA226AIDGSR; INA226; JLCPCB C49851
U6: 93LC56BT-I/OT; EEPROM; JLCPCB C190271
U7: ICE40UP5K-SG48I; QFN48_L-ASC10_ICE40ULTRAPLUS_MACHXO2_LAT
U8: W25Q32JVSSIQ; FLASH; LCSC Part C82344
U10, U11: 20m; R20m; LCSC Part C4944045
U12: TPS62240DRVR; Vreg1_2; JLCPCB C398345

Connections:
1.2: C4.1, C21.1, L6.1, R17.1, TP17.1, U4.10 (VIN+), U10.2
3.3: C1.1, C20.1, C25.1, C27.1, C28.1, C36.2, C46.1, D7.2 (A), L1.1, L2.1, L4.1, R15.1, R18.1, R20.1, TP16.1, U1.12 (VCCIO), U1.24 (VCCIO), U1.34 (RESET#), U1.39 (VCCD), U1.40 (VREG), U1.46 (VCCIO), U2.5 (FB), U5.10 (VIN+), U6.6 (VCC), U11.2, U12.4 (EN), U12.5 (VIN)
+1V2: C40.1, C41.1, C42.1, C47.1, C48.1, C49.1, C50.1, J6.1, J6.2, J10.9, J10.10, J10.11, R21.2, U4.8 (VBUS), U4.9 (VIN-), U7.5 (VCC), U7.30 (VCC), U10.1
+2V5: C2.1, D7.1 (K), JP1.1 (A), TP18.1
+3V3: C3.1, C6.1, C23.1, C32.1, C38.1, C39.1, C43.1, C44.1, C45.1, C51.1, C52.1, C53.1, C55.1, C5393554.1 (A), D1.2 (A), D3.2 (A), D4.2 (A), D5.2 (A), D6.2 (A), J3.1, J3.2, J10.4, J10.5, J10.6, JP1.3 (B), OSC1.1 (TRI-STATE(STBY)), OSC1.4 (VDD), PMOD_OLED1.1, PMOD_OLED1.2, PMOD_TMP2.1, PMOD_TMP2.2, R3.1, R7.1, R8.1, R13.1, R14.1, R19.2, R22.1, R23.2, R26.1, R32.1, R36.1, R37.1, U3.8 (VCC), U4.6 (VS), U5.2 (A0), U5.6 (VS), U5.8 (VBUS), U5.9 (VIN-), U7.1 (VCCIO_2), U7.22 (SPI_Vccio1), U7.33 (VCCIO_0), U8.8 (VCC), U11.1; also elsewhere on the board
+5V: C5.1, C19.2, C22.1, D2.2 (A), D13.1 (K), J5.1, J5.2, J10.1, J10.2, J10.3, SW7.2, U2.1 (EN), U2.2 (VIN), U2.3 (VIN)
/BLED: R16.2, U7.23 (IOT_37a)
/B_LED: R27.2, U7.40 (RGB1)
/DC_PMOD: PMOD_OLED1.12, U7.36 (IOT_48b)
/D_M: J1.A7 (DN1), J1.B7 (DN2), U1.6 (DM)
/D_P: J1.A6 (DP1), J1.B6 (DP2), U1.7 (DP)
/EE_CLK: R20.2, U1.44 (EECLK), U6.4 (CLK)
/EE_CS: R18.2, U1.45 (EECS), U6.5 (CS)
/EE_DAT: R11.1, U1.43 (EEDATA), U6.3 (DI)
/FPGA_CLK: U3.6 (1Y), U7.20 (IOB_25b_G3)
/FT_CLK: U1.1 (OSCI), U3.3 (2Y)
/FT_VCORE: C37.1, U1.38 (VCORE)
/GLED: R29.2, U7.21 (IOB_23b)
/G_LED: R25.2, U7.39 (RGB0)
/I2C_SCL: PMOD_TMP2.7, PMOD_TMP2.8, R23.1, U7.13 (IOB_24a)
/I2C_SDA: PMOD_TMP2.5, PMOD_TMP2.6, R19.1, U7.12 (IOB_22a)
/OLED: R9.1, U7.43 (IOT_49a)
/PIN1: J4.1, U7.11 (IOB_20a)
/PIN2: J4.2, U7.10 (IOB_18a)
/PIN3: J4.3, U7.9 (IOB_16a)
/PIN4: J4.4, U7.6 (IOB_13b)
/PIN5: J4.5, U7.4 (IOB_8a)
/PIN6: J4.6, U7.3 (IOB_9b)
/PIN7: J4.7, U7.2 (IOB_6a)
/PIN8: J4.8, U7.48 (IOB_4a)
/PIN9: J4.9, U7.47 (IOB_2a)
/PIN10: J4.10, U7.46 (IOB_0a)
/PIN11: J4.11, U7.45 (IOB_5b)
/PMOD_CLK: PMOD_OLED1.5, U7.27 (IOT_38b)
/PMOD_SDO: PMOD_OLED1.9, U7.32 (IOT_43a)
/PMOD_SS: PMOD_OLED1.11, U7.35 (IOT_46b_G0)
/RES_PMOD: PMOD_OLED1.10, U7.34 (IOT_44b)
/RLED: R28.1, U7.38 (IOT_50b)
/R_LED: R24.1, U7.41 (RGB2)
/SCK: R26.2, U1.13 (ADBUS0), U7.15 (IOB_34a_SPI_SCK), U8.6 (CLK)
/SCL: J2.1, J2.2, R22.2, U4.5 (SCL), U5.5 (SCL), U7.25 (IOT_36b)
/SDA: J9.1, J9.2, R7.2, U4.4 (SDA), U5.4 (SDA), U7.26 (IOT_39a)
/SDI: U1.15 (ADBUS2), U7.17 (IOB_33b_SPI_SI), U8.2 (DO（IO1）)
/SDO: U1.14 (ADBUS1), U7.14 (IOB_32a_SPI_SO), U8.5 (DI（IO0）)
/SD_IO2: R36.2, U7.19 (IOB_29b), U8.3 (IO2)
/SD_IO3: R32.2, U7.18 (IOB_31b), U8.7 (IO3)
/SS: R37.2, U1.17 (ADBUS4), U7.16 (IOB_35b_SPI_SS), U8.1 (~CS)
/VBAT: PMOD_OLED1.8, U7.31 (IOT_42b)
/VCC_PLL: C34.1, C35.1, R21.1, U7.29 (VCCPLL)
/VDDC: PMOD_OLED1.6, U7.28 (IOT_41a)
/VPHY: C29.1, C31.1, L4.2, U1.3 (VPHY)
/VPLL: C30.1, C33.1, L2.2, U1.8 (VPLL)
/cdone: R10.2, TP19.1, U1.19 (ADBUS6), U7.7 (CDONE)
unnamed: C10.1, L3.2, SW7.1
unnamed: C5393554.3 (BK), R27.1
unnamed: C5393554.4 (GK), R25.1
unnamed: C5393554.2 (RK), R24.2
unnamed: D1.1 (K), R29.1
unnamed: D2.1 (K), R6.2
unnamed: D3.1 (K), R10.1
unnamed: D4.1 (K), R28.2
unnamed: D5.1 (K), R16.1
unnamed: D6.1 (K), R9.2
unnamed: J1.A5 (CC1), R1.1
unnamed: J1.B5 (CC2), R2.1
unnamed: J1.A4 (VBUS), J1.A9 (VBUS), J1.B4 (VBUS), J1.B9 (VBUS), L3.1, TP3.1
unnamed: C56.1, C57.1, JP1.2 (C), U7.24 (VPP_2V5)
unnamed: L1.2, U2.7 (SW), U2.8 (SW)
unnamed 68: OSC1.3 (OUTPUT), U3.2 (1A), U3.5 (2A); also elsewhere on the board
unnamed: TP6.1, U1.21 (ACBUS0)
unnamed: TP15.1, U1.25 (ACBUS1)
unnamed: TP14.1, U1.26 (ACBUS2)
unnamed: TP13.1, U1.27 (ACBUS3)
unnamed: TP11.1, U1.28 (ACBUS4)
unnamed: TP10.1, U1.29 (ACBUS5)
unnamed: TP9.1, U1.30 (ACBUS6)
unnamed: TP8.1, U1.31 (ACBUS7)
unnamed: TP7.1, U1.32 (ACBUS8)
unnamed: TP12.1, U1.33 (ACBUS9)
unnamed: TP4.1, U1.16 (ADBUS3)
unnamed: TP5.1, U1.18 (ADBUS5)
unnamed: R5.2, U1.5 (REF)
unnamed: C24.1, U1.37 (VCCA)
unnamed: R11.2, R15.2, U6.1 (DO)
unnamed: C4.2, R12.1, R17.2, U12.3 (FB)
unnamed: L6.2, U12.1 (SW)

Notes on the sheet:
POWER SUPPLY
C273394
ORANGE
FPGA
BLUE
EXTERNAL CONNECTORS
RED
EEPROM
GREEN
FTDI
GREEN
BUTOANE SI LEDURI
POWER MEASUREMENT
12 MHz CLOCK
0.6A
VOLTAGE REGULATORS
active low
FLASH

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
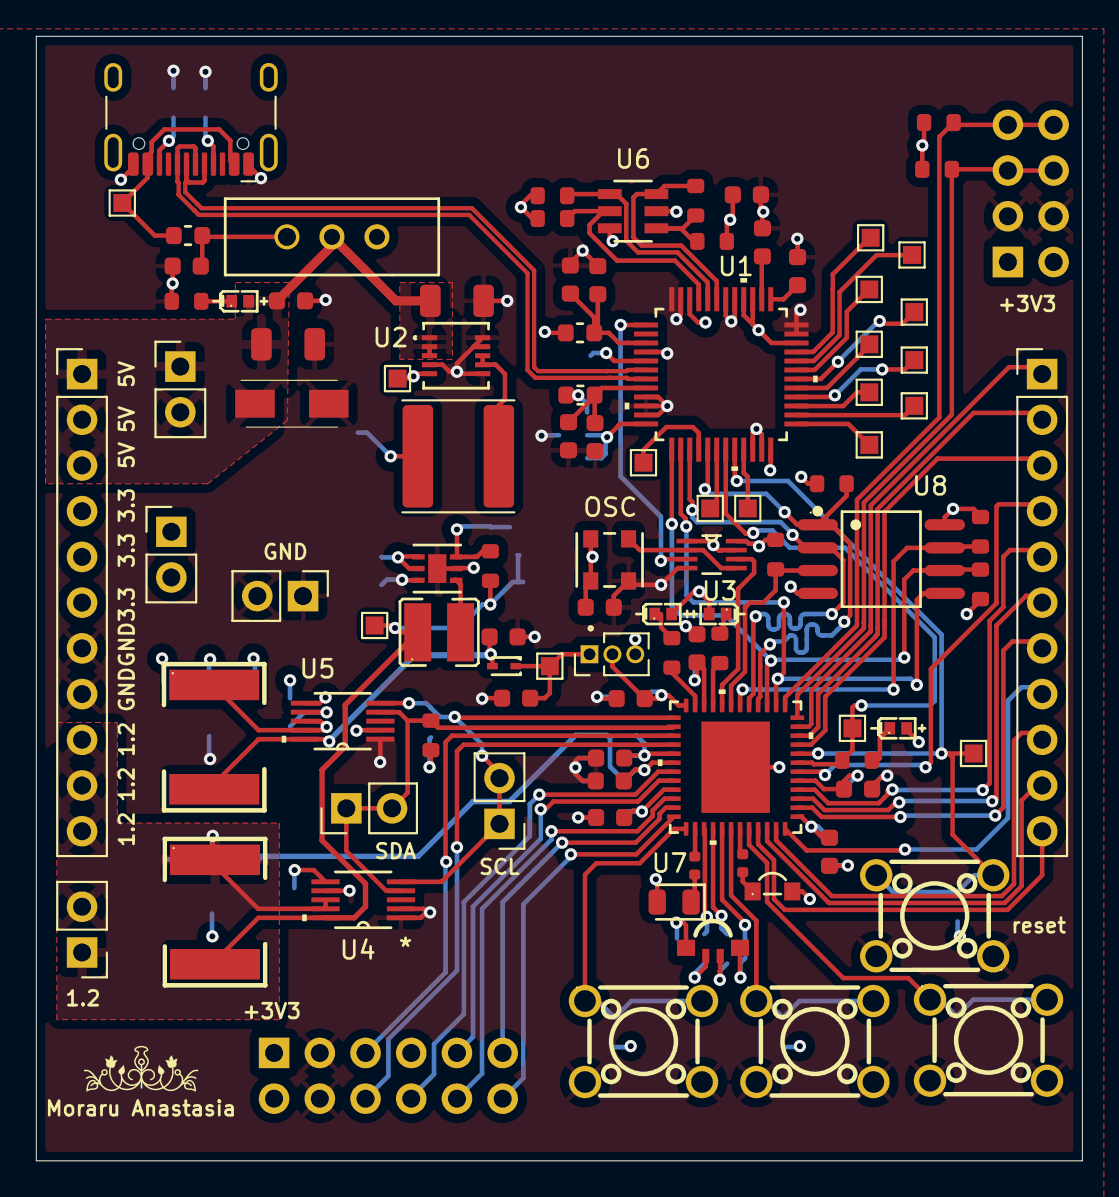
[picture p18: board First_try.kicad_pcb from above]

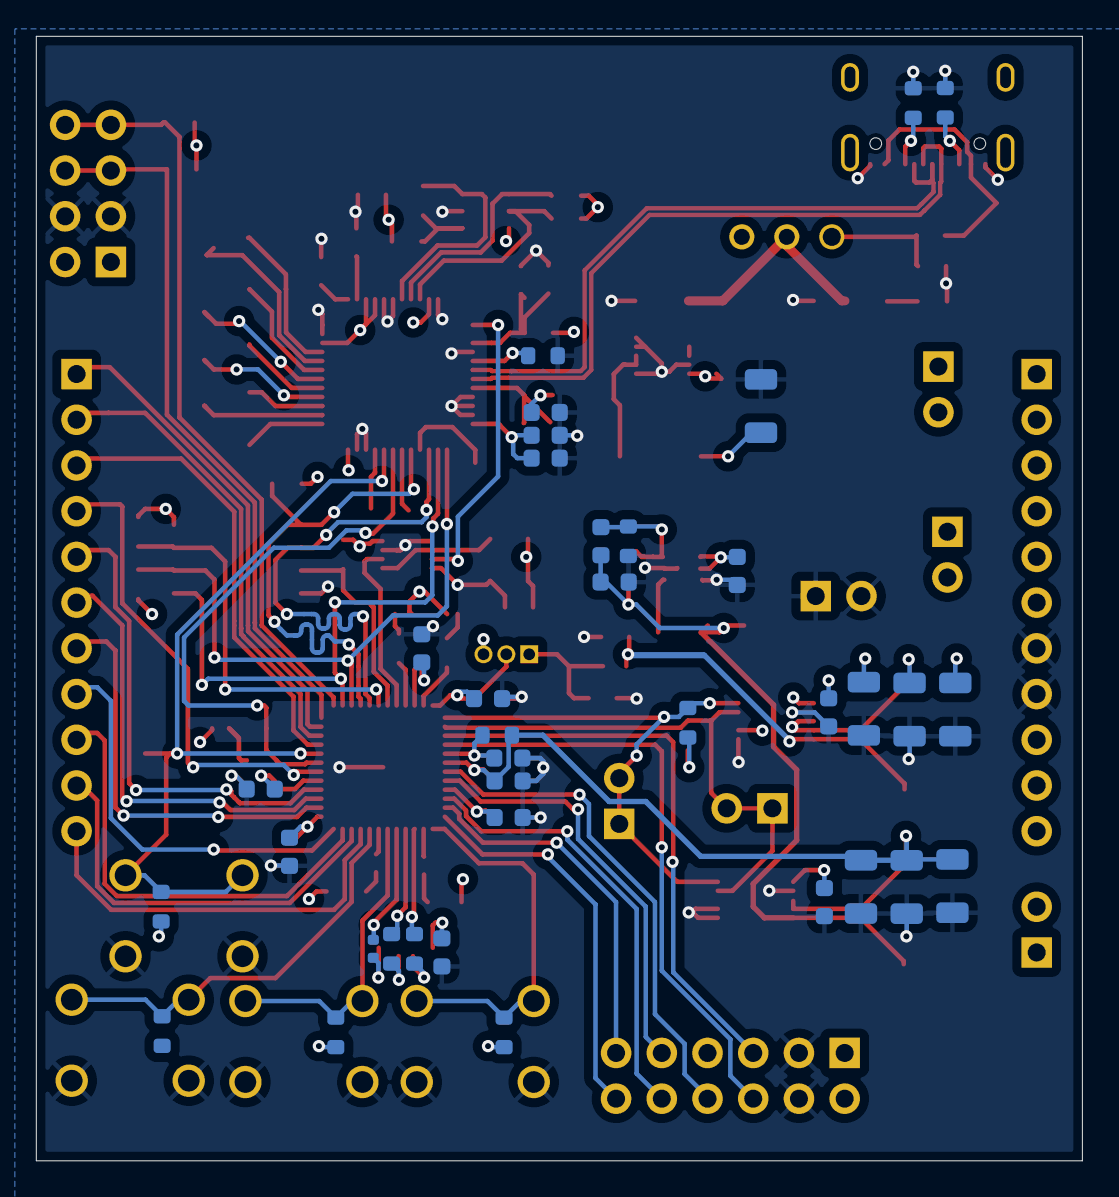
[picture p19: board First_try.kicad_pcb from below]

Board: 4 copper layers, 58.1 x 62.5 mm, 133 parts (36 on the bottom side), 83 nets.

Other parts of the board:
OSC: ASE-12.000MHZ-LC-T; ASE-3.2X2.5_ABR
R14#2: 10kΩ; R_0603
SW2#2: SW_Push; SW_push

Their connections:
+3V3: OSC.1 (TRI-STATE(STBY)), OSC.4 (VDD), R14#2.1; also elsewhere on the board
unnamed 68: OSC.3 (OUTPUT); also elsewhere on the board

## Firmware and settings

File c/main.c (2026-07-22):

/*
 * main.c - top level of picorv32 firmware
 * 06-30-19 E. Brombaugh
 */

#include <stdio.h>
#include "up5k_riscv.h"
//  #include "acia.h"
// #include "printf.h"
//  #include "spi.h"
//  #include "flash.h"
#include "clkcnt.h"
//  #include "ili9341.h"
//  #include "i2c.h"
//  #include "oledrgb.h"
//  #include "ina226.h"
// #include "dhry.h"

#define RED 0xB
#define ORANGE 0x7
#define GREEN 0xE

/*
 * main... duh
 */
void main()
{

	// uint32_t cnt, spi_id, i, j;

	/* test both SPI ports */
	// spi_init(SPI0);       // Mode 0 for Flash
	// spi_init_mode3(SPI1); // Mode 3 for OLED

	/* get spi flash id */
	// flash_init(SPI0);	// wake up the flash chip
	// spi_id = flash_id(SPI0);
	// printf("spi flash id: 0x%08X\n\r", spi_id);

	/*oled_init();
	oled_clear(BLACK);

	//i2c_init(I2C1);

	/* Program calibration register for both INA226 sensors */
	/*ina226_init(I2C1, 0x40);
	ina226_init(I2C1, 0x41);

	char buf[32];

	while (1)
	{
		int i;

		int32_t sum_v40 = 0;
		int32_t sum_p40 = 0;
		int32_t sum_v41 = 0;
		int32_t sum_p41 = 0;

		/* Average 10 measurements */
	/*for (i = 0; i < 10; i++)
	{
		sum_v40 += ina226_read_bus_mv(I2C1, 0x40);
		sum_p40 += ina226_read_power_uw(I2C1, 0x40);

		sum_v41 += ina226_read_bus_mv(I2C1, 0x41);
		sum_p41 += ina226_read_power_uw(I2C1, 0x41);

		clkcnt_delayms(50);
	}

	int32_t v40_mv = sum_v40 / 10;
	int32_t p40_uw = sum_p40 / 10;

	int32_t v41_mv = sum_v41 / 10;
	int32_t p41_uw = sum_p41 / 10;

	oled_clear(BLACK);

	sprintf(buf, "1.2V: %ld.%02ldV", v40_mv / 1000, (v40_mv % 1000) / 10);
	oled_drawstr(0, 0, buf, WHITE, BLACK);

	sprintf(buf, "%ld.%03ldmW", p40_uw / 1000, p40_uw % 1000);
	oled_drawstr(0, 16, buf, YELLOW, BLACK);

	sprintf(buf, "3.3V: %ld.%02ldV", v41_mv / 1000, (v41_mv % 1000) / 10);
	oled_drawstr(0, 32, buf, WHITE, BLACK);

	sprintf(buf, "%ld.%03ldmW", p41_uw / 1000, p41_uw % 1000);
	oled_drawstr(0, 48, buf, YELLOW, BLACK);

	clkcnt_delayms(1000);
}*/

	while (1)
	{
		uint32_t button_state = button_addr;
		uint8_t b1_pressed = !((button_state >> 0) & 1);

		gp_out = RED;

		if (b1_pressed)
		{
			clkcnt_delayms(1000);
			gp_out = ORANGE;
			clkcnt_delayms(2000);
			gp_out = GREEN;
			clkcnt_delayms(5000);
		}
	}

#if 0
	/* read some data */
	{
		uint8_t read[256];
		flash_read(SPI0, read, 0, 256);
		for (i = 0; i < 256; i += 8)
		{
			printf("0x%02X: ", i);
			for (j = 0; j < 8; j++)
			{
				printf("0x%02X ", read[i + j]);
			}
			printf("\n\r");
		}
	}
#endif

	/* Test LCD */
	/*	ili9341_init(SPI1);
		printf("LCD initialized\n\r");

	#if 1
		// color fill + text fonts
		ili9341_fillRect(20, 20, 200, 280, ILI9341_MAGENTA);
		ili9341_drawstr(120-44, (160-12*8), "Hello World", ILI9341_WHITE, ILI9341_MAGENTA);

		// test font
		for(i=0;i<256;i+=16)
			for(j=0;j<16;j++)
				ili9341_drawchar((120-8*8)+(j*8), (160-8*8)+(i/2), i+j,
					gp_outILI9341_GREEN, ILI9341_BLACK);

		clkcnt_delayms(1000);
	#endif */

#if 0
	/* test colored lines */
	{
		uint8_t rgb[3], hsv[3];
		uint16_t color;
		ili9341_fillScreen(ILI9341_BLACK);
		hsv[1] = 255;
		hsv[2] = 255;
		j=256;
		while(j--)
		{	
			for(i=0;i<320;i++)
			{
				hsv[0] = (i+j);
				
				ili9341_hsv2rgb(rgb, hsv);
				color = ili9342_Color565(rgb[0],rgb[1],rgb[2]);
#if 0
				ili9341_drawLine(i, 0, ILI9341_TFTWIDTH-1, i, color);
				ili9341_drawLine(ILI9341_TFTWIDTH-1, i, ILI9341_TFTWIDTH-1-i, ILI9341_TFTWIDTH-1, color);
				ili9341_drawLine(ILI9341_TFTWIDTH-1-i, ILI9341_TFTWIDTH-1, 0, ILI9341_TFTWIDTH-1-i, color);
				ili9341_drawLine(0, ILI9341_TFTWIDTH-1-i, i, 0, color);
#else
				ili9341_drawFastHLine(0, i, 240, color);
#endif
			}
		}
	}
	clkcnt_delayms(1000);
#endif

#if 0
	/* test image blit from flash */
	{
		uint16_t blit[ILI9341_TFTWIDTH*4];
		uint32_t blitaddr, blitsz;
		blitaddr = 0x200000;
		blitsz = ILI9341_TFTWIDTH*4*sizeof(uint16_t);
		for(i=0;i<ILI9341_TFTHEIGHT;i+=4)
		{
			flash_read(SPI0, (uint8_t *)blit, blitaddr, blitsz);
			ili9341_blit(0, i, ILI9341_TFTWIDTH, 4, blit);
			blitaddr += blitsz;
		}
	}
#endif

	/* Test I2C */
	/*	i2c_init(I2C0);
		printf("I2C0 Initialized\n\r");

		cnt = 0;
		while(1)
		{
			gp_out = (gp_out&~(7<<17))|((cnt&7)<<17);

			if(i2c_tx(I2C0, 0x1A, (uint8_t *)&cnt, 2))
				acia_putc('x');
			else
				acia_putc('.');

			cnt++;

	#if 0
			//simple echo
			if((c=acia_getc()) != EOF)
				acia_putc(c);
	#endif
			clkcnt_delayms(1000);
		} */
}

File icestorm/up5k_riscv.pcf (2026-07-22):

# CLOCK
set_io clk_12 20

# SPI FLASH
set_io spi0_mosi 17
set_io spi0_miso 14
set_io spi0_sclk 15
set_io spi0_cs0 16
set_io spi0_io2  19
set_io spi0_io3  18

# OLED
set_io spi1_mosi 32
set_io spi1_cs0 35
set_io spi1_dc 36
set_io spi1_res 34
set_io spi1_vccen 31
set_io spi1_pmoden 28
set_io spi1_sclk 27

# I2C PMOD
set_io i2c0_sda 12
set_io i2c0_scl 13

# I2C INA226 sensors
set_io i2c1_sda 26
set_io i2c1_scl 25

# set_io lcd_nrst 34
# set_io lcd_dc 36

# LEDS
set_io d1 21
set_io d2 23
set_io d3 38
set_io d4 43

set_io RGB0 39
set_io RGB1 40
set_io RGB2 41

# buttons
set_io b1 37
set_io b2 42
set_io b3 44

# serial
set_io RX 11
set_io TX 10

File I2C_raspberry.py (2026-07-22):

from machine import Pin, I2C
from time import sleep 
import struct

i2c = I2C(0, sda=Pin(4), scl=Pin(5), freq=100000)

INA226_ADDR1 = 0x40
INA226_ADDR2 = 0x41
R_SHUNT = 0.02 #in Ohms

REG_SHUNT_VOLTAGE = 0x01 #registers from DS
REG_BUS_VOLTAGE = 0x02

def read_s16(addr, reg):
    data = i2c.readfrom_mem(addr, reg, 2)
    return struct.unpack(">h", data)[0] #convert to decimal

def read_u16(addr, reg):
    data = i2c.readfrom_mem(addr, reg, 2)
    return struct.unpack(">H", data)[0]

while True:

    shunt_samples1 = []
    bus_samples1 = []

    shunt_samples2 = []
    bus_samples2 = []

    for _ in range(100):
        raw_shunt = read_s16(INA226_ADDR1, REG_SHUNT_VOLTAGE)
        raw_bus = read_u16(INA226_ADDR1, REG_BUS_VOLTAGE)

        shunt_samples1.append(raw_shunt)
        bus_samples1.append(raw_bus)

        raw_shunt = read_s16(INA226_ADDR2, REG_SHUNT_VOLTAGE)
        raw_bus = read_u16(INA226_ADDR2, REG_BUS_VOLTAGE)

        shunt_samples2.append(raw_shunt)
        bus_samples2.append(raw_bus)


    avg_shunt1 = sum(shunt_samples1) / len(shunt_samples1)
    avg_bus1 = sum(bus_samples1) / len(bus_samples1)
    avg_shunt2 = sum(shunt_samples2) / len(shunt_samples2)
    avg_bus2 = sum(bus_samples2) / len(bus_samples2)

    bus_v1 = avg_bus1 * 1.25e-3
    shunt_v1 = avg_shunt1 * 2.5e-6
    
    bus_v2 = avg_bus2 * 1.25e-3
    shunt_v2 = avg_shunt2 * 2.5e-6

    current_a1 = shunt_v1 / R_SHUNT
    power_w1 = bus_v1 * current_a1

    current_a2 = shunt_v2 / R_SHUNT
    power_w2 = bus_v2 * current_a2

    print("Bus voltage1:", bus_v1 , "V")
    print("Shunt voltage1:", shunt_v1, "V")
    print("Current1:", current_a1 * 1000, "mA")
    print("Power1:", power_w1 * 1000, "mW")
    print()

    print("Bus voltage2:", bus_v2 , "V")
    print("Shunt voltage2:", shunt_v2, "V")
    print("Current2:", current_a2 * 1000, "mA")
    print("Power2:", power_w2 * 1000, "mW")
    print()
    print("Total power:", (power_w2 + power_w1) * 1000 )
    print("**************")
    print()

    sleep(1)

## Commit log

2026-02-06 Initial project
    [10155435-00011LF.stp, AT25FF081A-SSHN-B.SchLib, AT25FF081A-SSHN-B.stp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]
2026-02-09 LEDs, Switches
    [First_try.kicad_sch]
2026-02-22 Reviewed USB-C plug
    [First_try.kicad_sch]
2026-03-01 Modificari dupa intalnirea de joi
    [First_try.kicad_sch]
2026-03-05 Replaced FPGA
    [First_try.kicad_sch]
2026-03-11 Modificari voltage regulator + LEDs
    [EDI2CAP.CFG, First_try.kicad_sch, SOT95P280X145-5N.PcbLib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]
2026-03-11 Added external connectors
    [First_try.kicad_sch]
2026-03-13 Footprints added
    [AT25FF081A-SSHN-B.SchLib, AT25FF081A-SSHN-B.stp, EDI2CAP.CFG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]
2026-03-30 Started the layout
    [First_try.kicad_pcb, First_try.kicad_sch]
2026-03-30 Started Layout
    [First_try-B_Mask.gbr, First_try-B_Paste.gbr, First_try-B_Silkscreen.gbr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]
2026-04-13 Layout modifications
    [First_try.kicad_pcb, First_try.kicad_sch]
2026-05-20 Last version
    [First_try-B_Mask.gbr, First_try-B_Paste.gbr, First_try-B_Silkscreen.gbr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]
2026-06-10 RISC-V added
    [First_try.kicad_pcb, First_try.kicad_sch]
2026-06-18 i2c.c changes
    [First_try.kicad_pcb]
2026-10-08 Add README for ICE40UP5K FPGA board
    Added detailed information about the ICE40UP5K low power FPGA board, including its design, programming, and integration with a microprocessor.
2026-10-08 Modify SPI modes link for better accessibility
    Updated the SPI modes link to open in a new tab.
